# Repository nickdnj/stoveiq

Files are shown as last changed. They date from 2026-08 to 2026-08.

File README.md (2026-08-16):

# StoveIQ -- Open Source Smart Cooking Monitor





An ESP32-S3 + MLX90640 thermal camera that turns any stove into a smart cooktop. Real-time heatmap, per-burner temperature tracking, thermal-aware recipe coaching, and cook session logging -- all running locally with zero cloud dependency.

**No cloud. No subscriptions. No app to install. Just open your browser.**

> **What am I looking at?** This started as a multipurpose kitchen gadget, became a
> commercial stove-safety product, got killed as a product, and came back as a personal
> build that lives over my own stove. That history explains most of the odd shapes in this
> repo -- see [Project History](#project-history). It is not a product, it is not for sale,
> and there is no roadmap to either.

## What it looks like

<table>
<tr>
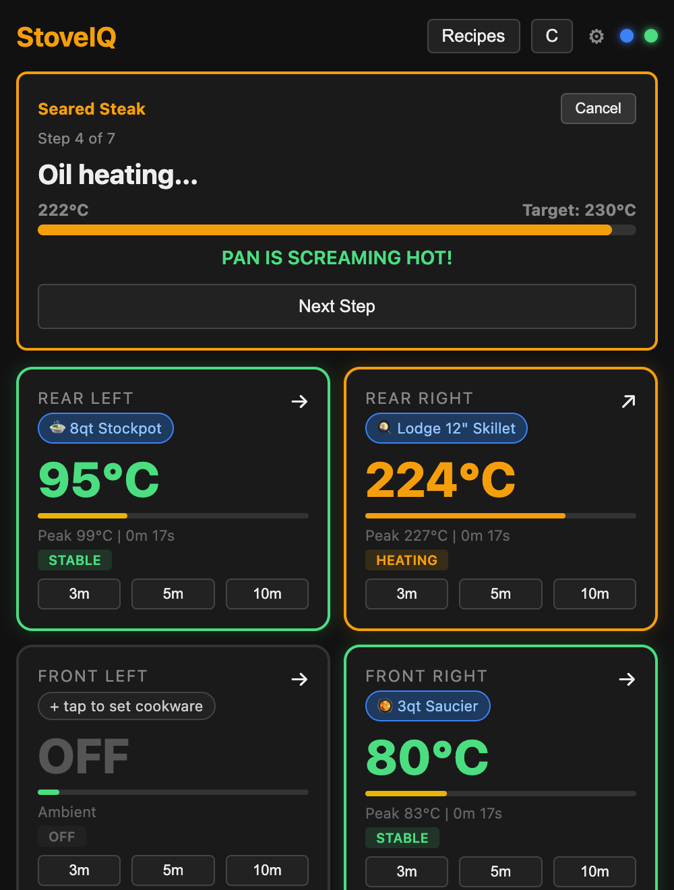
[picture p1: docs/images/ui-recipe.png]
Recipe coaching over live burner cards
<td width="33%"></td>
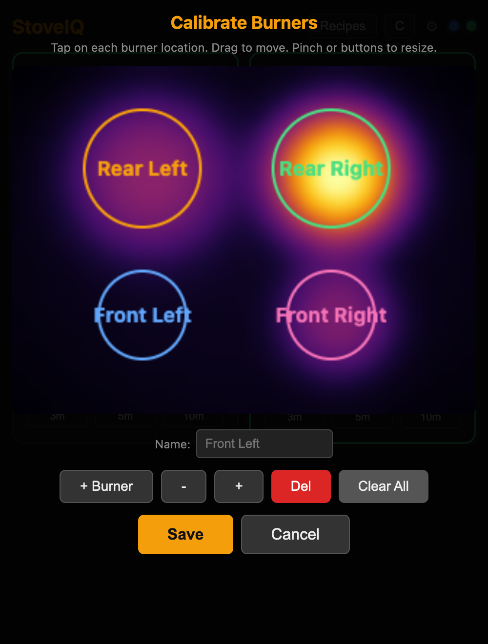
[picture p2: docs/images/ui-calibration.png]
Thermal heatmap with burner zones
<td width="33%"></td>
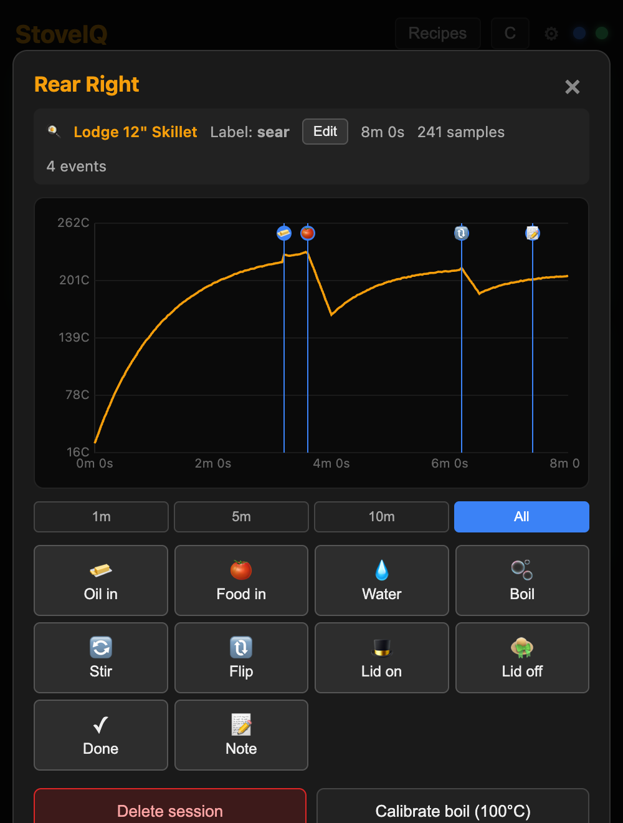
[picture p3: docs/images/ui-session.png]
Annotated cook session curve
<td width="33%"></td>
</tr>
<tr>
<td><b>Recipe coaching.</b> Steps advance on thermal triggers, not timers. Live burner cards underneath.</td>
<td><b>Calibration.</b> The 768-pixel heatmap, bilinear-upscaled, with burner zones tapped onto it.</td>
<td><b>Teaching mode.</b> A finished sear, replayed. The dips are the steak going in and the flip.</td>
</tr>
<tr>
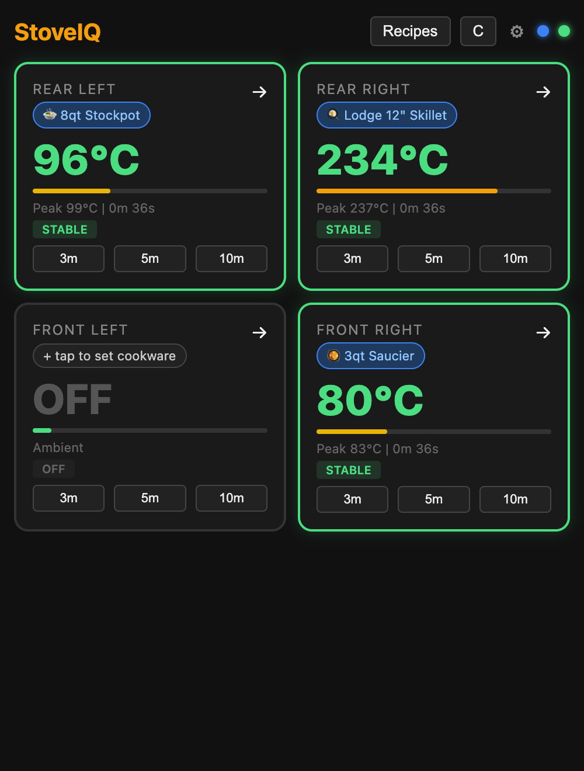
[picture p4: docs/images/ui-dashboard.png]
Burner dashboard
<td></td>
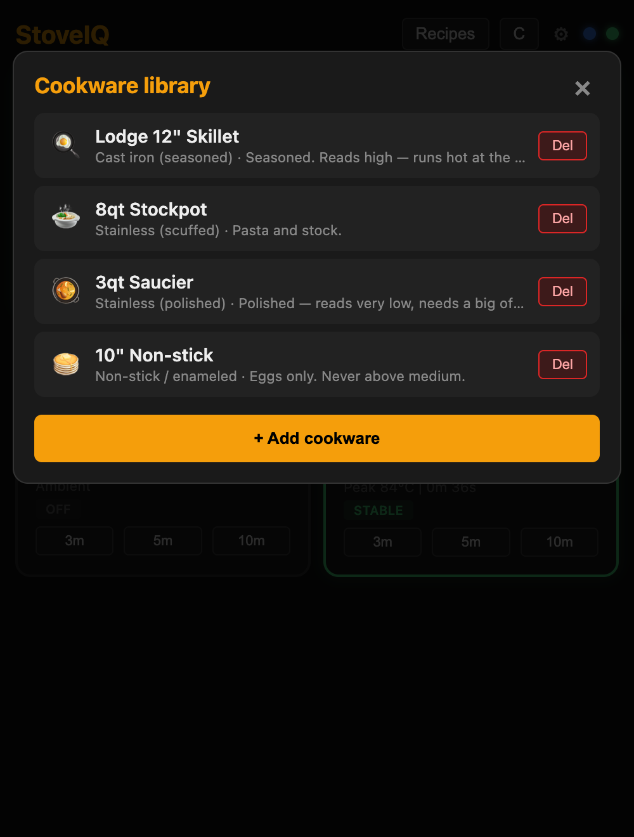
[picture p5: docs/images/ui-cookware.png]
Cookware library
<td></td>
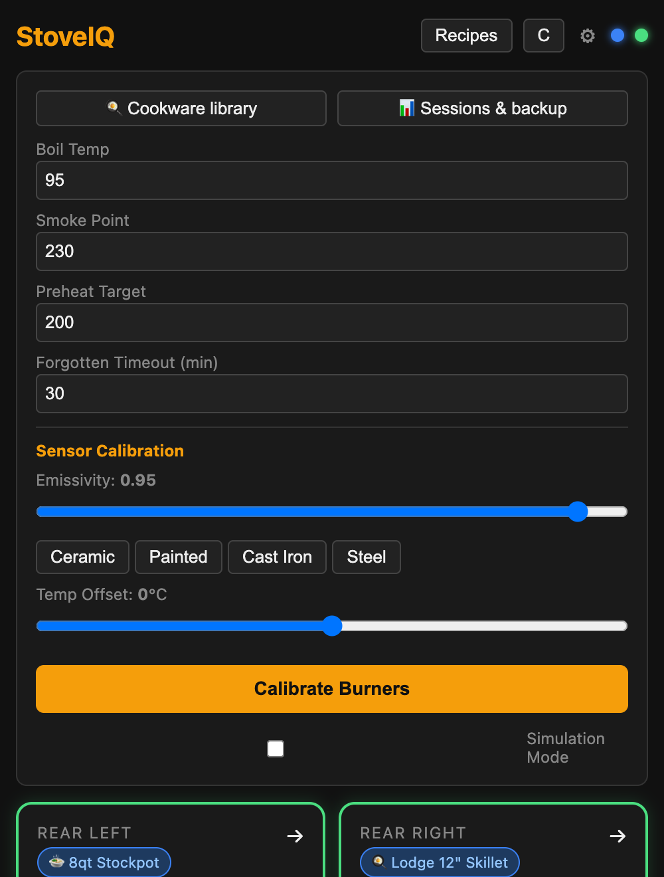
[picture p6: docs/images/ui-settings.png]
Settings and sensor calibration
<td></td>
</tr>
<tr>
<td><b>Dashboard.</b> Per-burner temperature, state, peak, and elapsed time.</td>
<td><b>Cookware library.</b> Emissivity is a property of the pot, so the pot is a first-class object.</td>
<td><b>Settings.</b> Alert thresholds and sensor calibration.</td>
</tr>
</table>

Real UI, synthetic thermal data — regenerate with
[`tools/ui-screenshots/`](tools/ui-screenshots/). Details and provenance in
[`docs/images/`](docs/images/).

## Features

- **Real-time thermal heatmap** -- 768-pixel IR view of your entire cooktop at 4Hz, bilinear-upscaled
- **Per-burner tracking** -- Auto-detects up to 4 burner zones with temperature, state, and trends
- **Recipe coaching** -- JSON state machines with thermal triggers (boil detected, pan preheated, oil in)
- **Cookware calibration** -- Emissivity is per-pot, not per-stove; calibration is a (burner x cookware) pair
- **Teaching mode** -- Tag what happened during a cook ("oil in", "rolling boil") and annotate the temp curve afterward
- **Smart alerts** -- Boil detection, oil smoke point warnings, pan preheated, forgotten burner
- **Runs as a PWA** -- HTTPS + Screen Wake Lock, so your phone stays awake on the counter while you cook
- **100% local** -- All processing on-device, data never leaves your kitchen
- **Works on any stove** -- Gas, electric coil, glass ceramic, induction

## Build Your Own

### Parts List (~$103 from Adafruit)

| Part | Price | Source |
|---|---|---|
| ESP32-S3-DevKitC-1-N8R8 | ~$16 | Adafruit (PID 5312) |
| MLX90640 IR Camera Breakout 110deg FoV | ~$75 | Adafruit (PID 4469) |
| Jumper wires (4x F-F) | ~$1 | Any supplier |
| USB-C cable + 5V adapter | ~$8 | Any supplier |
| 1.5" Schedule 40 PVC pipe (enclosure) | ~$3 | Hardware store |

MLX90640 modules run ~$25-35 on AliExpress, which brings the whole build closer to $50.

A custom PCB meant to replace the devkit lives in [`hardware/pcb/`](hardware/pcb/), but it
is a placement study rather than a board: it has no MCU on it, no routing, and 58 DRC
violations. Build the devkit version. See [Hardware](#hardware) below.

### Wiring

```
ESP32-S3 DevKit     MLX90640 Breakout
--------------      ----------------
3V3          -----> VIN
GND          -----> GND
GPIO 1 (SDA) -----> SDA
GPIO 2 (SCL) -----> SCL
```

### Flash Firmware

```bash
# Install PlatformIO
pip install platformio

# Clone and build
git clone https://github.com/nickdnj/stoveiq.git
cd stoveiq/firmware
pio run -e esp32s3 -t upload
```

The entire web UI is embedded in the firmware binary (`src/web_server.c`), so there is no
separate filesystem upload step. A SPIFFS partition exists and is mounted if populated,
but `firmware/data/` currently ships empty on purpose.

### Connect

1. Power on the device via USB-C
2. Connect to **StoveIQ** WiFi network (open, no password)
3. Open **https://192.168.4.1** in your browser
4. Accept the self-signed certificate warning (one time per device)
5. See your stove in thermal vision

To connect to your home WiFi (for access from any device):
- Use the **ESP BLE Prov** app (iOS/Android) with PoP: `stoveiq-setup`
- Or configure via the web UI settings page

Once on your network the device is reachable at **https://stoveiq.local** via mDNS. Port 80
stays up only to 301-redirect to HTTPS -- the Screen Wake Lock API that keeps your phone
awake while cooking requires a secure context, so plain HTTP is not an option.

## How It Works

```
MLX90640 IR Camera (24x32 pixels, 4Hz)
        |
        v
ESP32-S3 (FreeRTOS)
  Task 1: Sensor Read (Core 1)    -- I2C frame acquisition
  Task 2: Cooking Engine (Core 0) -- CCL burner detection + recipes + alerts
  Task 3: Web Server (Core 0)     -- HTTPS + WebSocket streaming
        |
        v
Browser (any device on WiFi)
  WebSocket binary frames --> Canvas 2D heatmap
  WebSocket JSON status   --> Per-burner dashboard
  localStorage            --> Cookware library, cook sessions, learned offsets
```

### Burner Detection

Connected Component Labeling (CCL) on thresholded thermal image:
1. Binary mask: pixels > ambient + 30C
2. Two-pass CCL with 8-connectivity
3. Filter noise (< 4 pixels) and spurious regions (> 200 pixels)
4. Rank by total heat, track centroids across frames
5. Classify state: OFF / HEATING / STABLE / COOLING via dT/dt

### Calibration

Calibration is two axes, not one:

- **Burner** -- a fixed spatial region of interest on the sensor. Set once by tapping the heatmap.
- **Cookware** -- a thermal property, picked per cook from a user-managed library.

The reason is emissivity: cast iron reads at ~0.95, polished stainless at ~0.05-0.16. A single
global emissivity value is wrong for nearly every pot on the stove. Offsets are stored per
(burner x cookware) pair and applied at display time only -- sessions keep raw temperatures so
the data stays reinterpretable. See [`docs/phase1-cookware-teaching.md`](docs/phase1-cookware-teaching.md).

---

## Hardware

All of it drawn in free and open-source tools -- KiCad for the board, OpenSCAD for the
enclosure. Every image below is generated from source by
[`hardware/render.sh`](hardware/render.sh), not exported by hand.

### Enclosure -- built, and holding the thing up right now

1.5" Schedule 40 PVC pipe split lengthwise. The lower half holds the MLX90640 behind a
14mm window, the upper half holds the devkit, zip ties clamp them together, and the tube
rotates inside a printed cradle so you can aim it and lock the angle.

| Assembled tube | Cabinet bracket | Sensor half |
|---|---|---|
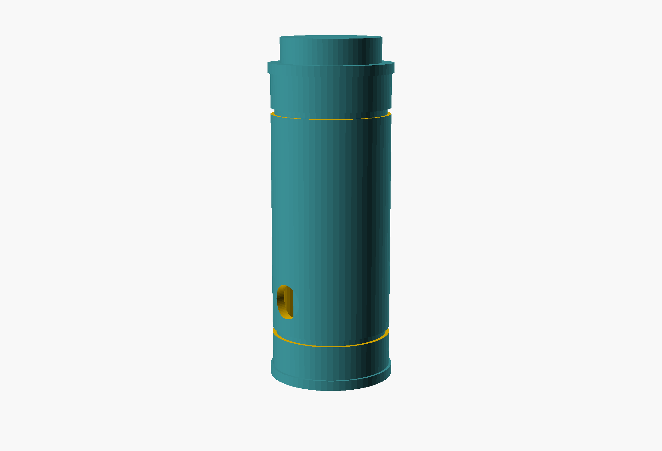
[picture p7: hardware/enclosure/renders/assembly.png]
Assembled enclosure
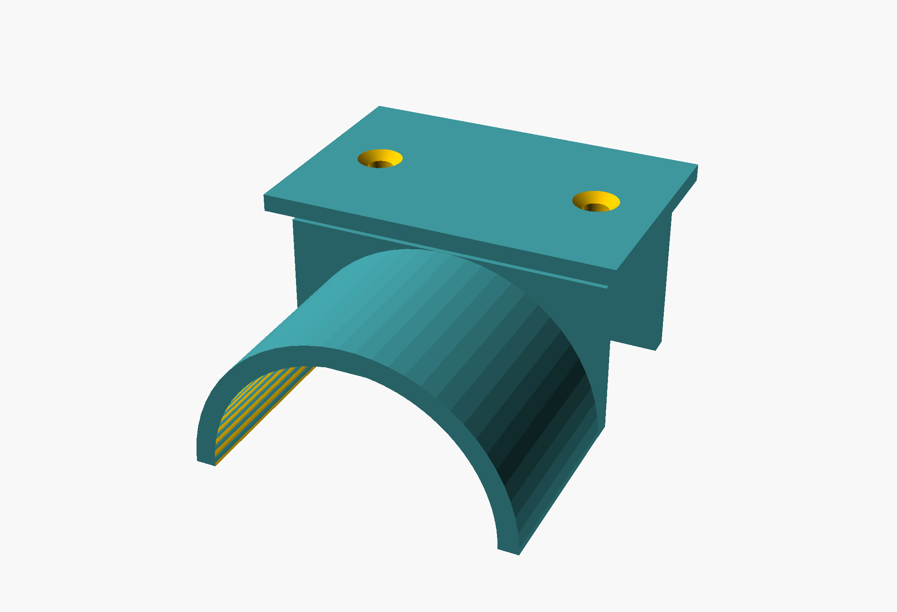
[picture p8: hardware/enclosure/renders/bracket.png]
Mounting bracket
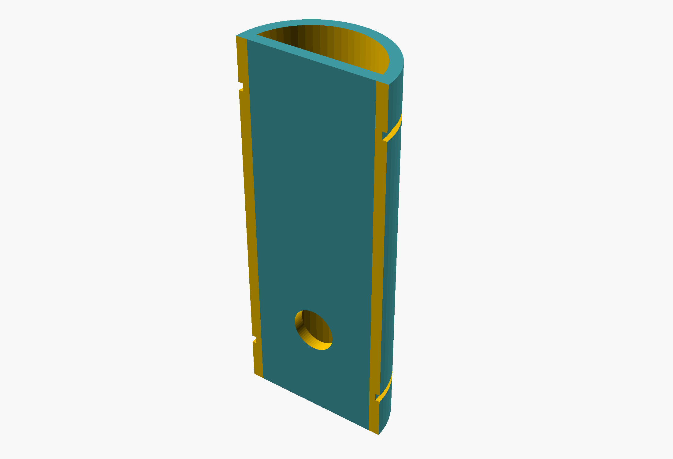
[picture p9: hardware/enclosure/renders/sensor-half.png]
Sensor half
|  |  |  |

Parametric, so you can re-cut it for your own cabinet before printing. Build guide:
[`docs/enclosure-build.md`](docs/enclosure-build.md) · Models and dimensions:
[`hardware/enclosure/`](hardware/enclosure/)

### Custom PCB -- drawn, not finished

A 45x35mm two-layer board to replace the devkit and breakout with one assembly.

| Schematic | 3D | Top copper |
|---|---|---|
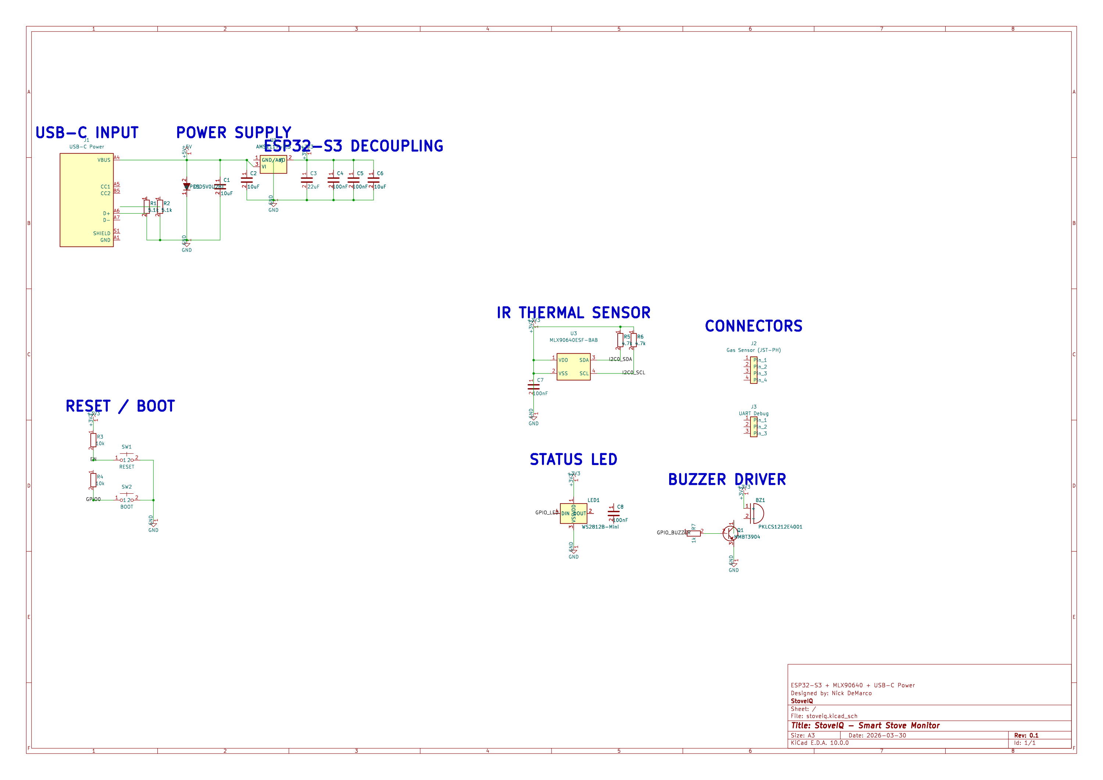
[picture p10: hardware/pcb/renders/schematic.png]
Schematic
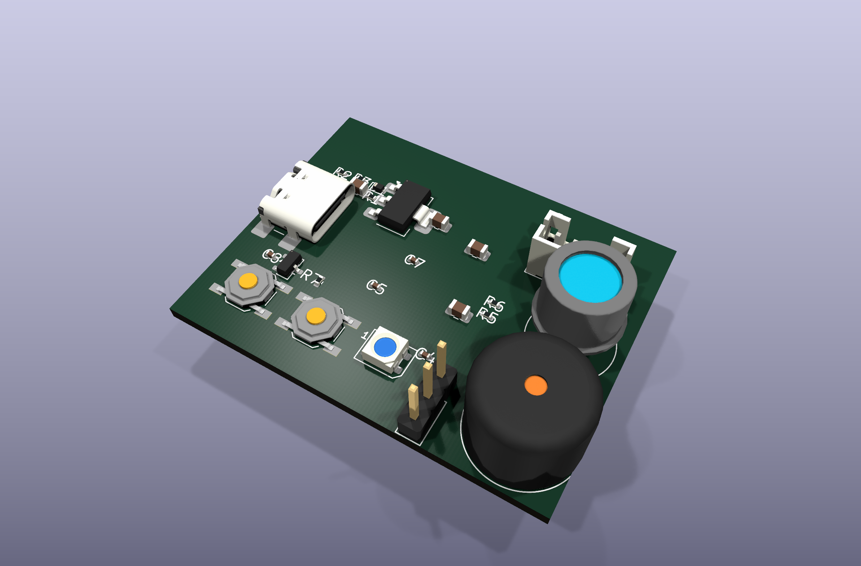
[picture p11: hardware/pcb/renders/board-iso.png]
Board 3D
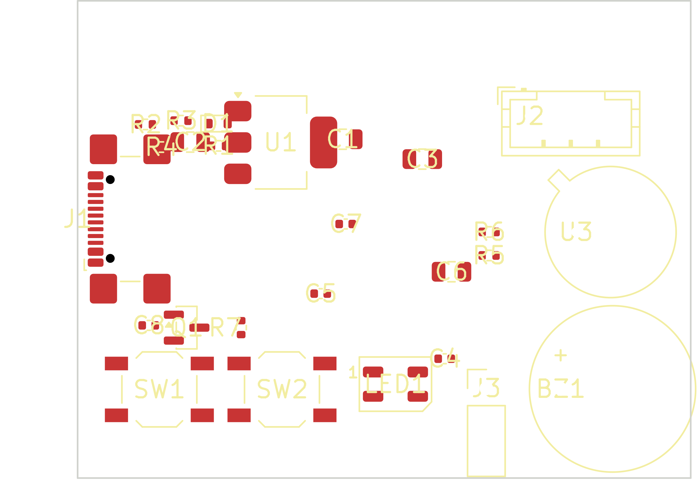
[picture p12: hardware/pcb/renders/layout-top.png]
Top layer
|  |  |  |

That third image is the honest one: **there is not a single trace on this board.** The
support circuitry is captured -- USB-C input, 3.3V regulation, the thermal sensor, an RGB
status LED, a piezo buzzer, reset and boot buttons -- but the ESP32-S3 module was never
placed, so every GPIO net dangles, and nothing is routed.

| | |
|---|---|
| Schematic capture | Partial -- everything except the MCU |
| Routing | None. 0 tracks, 0 vias |
| DRC | 58 violations, including 2 shorts |
| Fabricated | Never |

Full accounting, BOM, and known issues: [`hardware/pcb/README.md`](hardware/pcb/README.md).
If you want to finish it, the files are all here and the licence is permissive.

### Built with

| Tool | Licence | Used for |
|---|---|---|
| [KiCad](https://www.kicad.org/) 10 | GPL-3.0 | Schematic, layout, 3D raytracing, DRC, fab output |
| [OpenSCAD](https://openscad.org/) | GPL-2.0 | Parametric enclosure modelling |
| [FreeCAD](https://www.freecad.org/) | LGPL-2.1 | Alternative enclosure macro |
| [Freerouting](https://freerouting.org/) | AGPL-3.0 | Autorouting attempt |
| [PlatformIO](https://platformio.org/) + [ESP-IDF](https://github.com/espressif/esp-idf) | Apache-2.0 | Firmware build |
| [librsvg](https://gitlab.gnome.org/GNOME/librsvg) | LGPL-2.1 | SVG to PNG for these images |

```bash
brew install kicad openscad librsvg   # or: apt install kicad openscad librsvg2-bin
hardware/render.sh
```

---

## Project History

Worth reading if you are trying to understand why an open-source hobby repo contains a
provisional patent's worth of thermal research, a Kickstarter-grade BOM, and a KiCad board
nobody fabricated. The short version: this project was three different things in four weeks.

| When | What it was |
|---|---|
| Mar 25, 2026 | A multipurpose kitchen gadget idea |
| Mar 26-27, 2026 | A commercial product, then narrowed to a safety-only device |
| Mar 28 - Apr 4, 2026 | A built safety product: firmware, Flutter app, cloud, CI |
| Apr 7, 2026 | Killed -- the commercial case did not survive research |
| Apr 9, 2026 onward | This repo: the original idea, built for one kitchen, in the open |

### 1. The multipurpose version

The first note described a thermal sensor under the range hood doing everything at once:
live heatmap, per-burner temperatures, boil detection, "did I leave the stove on" alerts,
oven monitoring, gas leak sensing, historical usage, a voice assistant hook. It was a
weekend-project wishlist, not a product. The only real constraint was the sensor -- the
MLX90640 was the cheapest array that reads to 300C, which is what ruled out the AMG8833
and set the whole hardware stack.

### 2. It turned into a product

Within a day it grew a full product-development package: PRD, architecture spec, UX spec,
sensor validation study, provisional patent draft, a BOM costed at 100 and 1,000 units
(~$25-37 landed), $199-229 MSRP, and a Kickstarter strategy benchmarked against Inirv
React's $176K raise. Cooking a thing for yourself had become launching a thing at people.

### 3. GStack narrowed it to a safety device

I ran the plan through GStack reviews -- an AI review pipeline (`/office-hours`,
`/plan-ceo-review`) that interrogates a plan the way a skeptical founder or investor would.
The verdict was uncomfortable and correct:

- **The buyer is not the cook.** Safety drives the purchase decision; cooking features drive
  daily engagement. The primary user is the adult child of a parent living alone, not me.
- **The MVP was still too broad.** It got stripped to a single question: *"Is Mom's stove on?"*
  Whole-frame max temperature, a duration timer, a push notification, a buzzer. That was all.
- **Everything I actually wanted got deferred.** Heatmap, per-burner detection, boil detection,
  calibration wizard, cooking history -- all pushed to "v2."

Fair review, honestly followed. Over the next week I built exactly that: safety-monitor
firmware, a Flutter app, Firebase push, MQTT, OTA updates, golden-vector tests, a security
review pass, CI. It lives in an archived private repo. None of it is in this one.

### 4. GStack then killed the product

A patent and competitive research pass on April 7 turned up
[Pippa Technologies](https://www.mypippa.me/) -- a UK company with **EP3908785B1**, granted
February 2025, covering IR thermal imaging for cooking appliance monitoring. Dragons' Den
funded, shipping at GBP 179.99 plus a subscription, on Amazon UK, with a US expansion in
progress. Meanwhile Cooksy, the closest thermal-cooking product, appeared to be retreating
from its $299-699 cooking-only position.

Add the rest of the arithmetic for a solo builder: FCC plus likely UL certification, and
open-ended liability for a device whose entire promise is *"we will warn you before the fire."*
The commercial case did not hold.

*None of that is a legal conclusion.* No freedom-to-operate opinion was ever commissioned.
It was a judgment call -- the kind where you do not want to find out the hard way.

I then researched seven other markets for the identical hardware stack: electrical panel
thermal monitoring (the best-graded of them, with a proven insurance distribution channel),
3D printer fire detection, dryer lint fires, EV charging, solar hotspots, beehives, server
rooms. All of them were more viable than the stove. I did not chase any of them, because
none of them were the thing I wanted in my kitchen.

### 5. Pivot back to just... my stove

On April 9 the project restarted as what it had been on day one, minus the ambition.

**Dropped:** company, Kickstarter, patent, cloud, MQTT, Flutter app, app store,
subscription, caregiver dashboard, and every safety claim.

**Kept:** the hardware, and the thing I actually wanted.

A fresh public repo was necessary anyway -- the old one had WiFi and MQTT credentials
committed in its history -- so it was archived private and this one started clean. The
happy accident: every cooking feature GStack had correctly cut as "v2 nice-to-have" became
the entire point again, because there was no longer a product for them to be a distraction
from.

That is why this repo is local-first, ships no cloud, makes no safety promises, and serves
its UI off an ESP32 instead of an app store.

### 6. Where it is now

Mounted over my stove and used for real cooking. Since the pivot it has grown recipe state
machines, HTTPS so the phone's wake lock works, cookware-based calibration, and a teaching
mode that captures labeled cook sessions -- a corpus for phase-aware calibration later. The
KiCad board and enclosure models landed in August 2026. The enclosure is printed and in
use; the board never got past component placement and has never been fabricated.

### Does it have economic value?

Honest answer: no idea, and I stopped trying to find out -- which was the point of stopping.

What I do know: as a commercial *safety* device the path is blocked, expensive, and legally
exposed for one person. As a *cooking* product the nearest comparable retreated from that
price point. As a personal build it has been worth every hour.

The software is MIT and the hardware is CERN-OHL-S-2.0. If you see the market I could not,
the files are all here -- schematics, board, enclosure, firmware, recipes. Take it.

---

## Repo Structure

```
stoveiq/
  firmware/
    src/              # Firmware source (C, ESP-IDF) -- web UI embedded in web_server.c
    include/          # Shared headers
    test/             # Unity test suite
    emulator/         # Desktop thermal emulator + scenarios
    lib/MLX90640/     # Melexis sensor driver
  hardware/
    render.sh         # Regenerates every hardware image from source
    pcb/              # KiCad 10 project -- schematic, layout, fab outputs
      renders/        #   Generated: schematic, layer plots, 3D views
    enclosure/        # PVC tube + wedge box (OpenSCAD, FreeCAD macro)
      renders/        #   Generated: assembly, parts, bracket
  enclosure/          # Byte-identical copy of hardware/enclosure/stoveiq_enclosure.scad,
                      # kept so the old path still resolves
  tools/
    ui-screenshots/   # Runs the web UI on a desktop with synthetic thermal data
  recipes/            # Community recipe JSON state machines + schema
  docs/
    images/           # UI screenshots used on this page
  video/              # Unproduced draft: script, storyboard, assembly pipeline
```

Enclosure files are OpenSCAD/FreeCAD sources, not pre-sliced STLs -- render your own.

## Development

### Desktop Emulator

Build and run without hardware using the thermal scene emulator:

```bash
cd firmware
pio run -e emulator
.pio/build/emulator/program
```

### Run Tests

```bash
cd firmware
pio test -e emulator
```

23 tests across two suites -- `test/test_sensor/` (frame parsing, max/ambient extraction,
emulator scenarios) and `test/test_cooking_engine/` (burner detection, state machine).

### Building from a fresh clone

The self-signed TLS certificate is not in the repo -- `firmware/src/certs.h` embeds a
private key, so it is generated rather than committed. Run this once per clone before the
first ESP32 build:

```bash
./scripts/gen-cert.sh
```

### See the web UI without hardware

The interface is embedded in the firmware as a C string, and the emulator build excludes
`web_server.c` -- so there is normally no way to look at the UI without flashing a board.
[`tools/ui-screenshots/`](tools/ui-screenshots/) extracts it and serves it locally against
a synthetic thermal feed that speaks the firmware's real WebSocket protocol.

```bash
cd tools/ui-screenshots
pip install aiohttp
python3 extract.py && python3 server.py --recipe   # http://127.0.0.1:8770
```

## Contributing

Contributions welcome -- especially:
- Recipes (see [`recipes/README.md`](recipes/README.md) for the schema and PR template)
- Web UI improvements (`firmware/src/web_server.c`)
- New cooking alert types
- Enclosure variants for different mounting scenarios
- Translations

Bear in mind what this project is: a personal build shared in the open. Issues and PRs get
looked at when there is time, and "does this make it better in my kitchen?" is a legitimate
review criterion.

## License

- **Software:** [MIT](LICENSE-SOFTWARE)
- **Hardware:** [CERN-OHL-S-2.0](LICENSE-HARDWARE)

## Inspired By

- [Combustion Inc](https://combustion.inc/) -- Smart cooking thermometer with predictive algorithms (internal meat temps via probe). StoveIQ provides the complementary view: surface thermal imaging of the entire cooktop from above.

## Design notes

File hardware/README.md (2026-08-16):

# StoveIQ Hardware

Everything mechanical and electrical, designed end-to-end in free and
open-source tools. No licence, no seat, no cloud account — clone the repo and
open the files.

| Directory | What | Tool | Status |
|---|---|---|---|
| [`pcb/`](pcb/) | Custom ESP32-S3 + MLX90640 board, 45 × 35 mm | KiCad 10 | **Placement study** — no MCU, unrouted, 58 DRC violations |
| [`enclosure/`](enclosure/) | PVC split-tube housing + cabinet bracket | OpenSCAD | **Built** — this is what is mounted over the stove |
| [`enclosure/`](enclosure/) | Wedge box for the custom board | OpenSCAD | Modelled only |

The honest summary: **the enclosure is real and the board is not.** The device
in daily use is an ESP32-S3 devkit and an MLX90640 breakout wired together and
zip-tied inside a length of PVC pipe. The custom PCB was drawn to replace them
and never finished.

---

## The toolchain

| Tool | Licence | Used for |
|---|---|---|
| [KiCad](https://www.kicad.org/) 10 | GPL-3.0 | Schematic capture, PCB layout, 3D raytracing, DRC, fab output |
| [OpenSCAD](https://openscad.org/) 2021.01 | GPL-2.0 | Parametric enclosure modelling and rendering |
| [FreeCAD](https://www.freecad.org/) | LGPL-2.1 | Alternative enclosure macro (see `enclosure/`) |
| [Freerouting](https://freerouting.org/) | AGPL-3.0 | Autorouting attempt (`pcb/stoveiq.dsn` / `.ses`) |
| [librsvg](https://gitlab.gnome.org/GNOME/librsvg) | LGPL-2.1 | SVG → PNG for the images on GitHub |
| [PlatformIO](https://platformio.org/) + [ESP-IDF](https://github.com/espressif/esp-idf) | Apache-2.0 | Firmware build (see `../firmware/`) |

Every image in this repository is generated from source by
[`render.sh`](render.sh) — no screenshots taken by hand, nothing drawn in a
proprietary tool.

```bash
# macOS
brew install kicad openscad librsvg

# Debian / Ubuntu
apt install kicad openscad librsvg2-bin

# Then, from the repo root
hardware/render.sh
```

Outputs land in `pcb/renders/` and `enclosure/renders/` and are committed, so
reading the GitHub page never requires installing anything.

---

## Where to start

- **Building one?** You want the devkit parts list in the
  [root README](../README.md#build-your-own) and the
  [enclosure build guide](../docs/enclosure-build.md).
- **Looking at the board?** [`pcb/README.md`](pcb/README.md) — full BOM,
  schematic, layout plots, and a frank list of what is wrong with it.
- **Printing a housing?** [`enclosure/README.md`](enclosure/README.md) —
  dimensions, print settings, STL export commands.

## Licence

Hardware is [CERN-OHL-S-2.0](../LICENSE-HARDWARE). Firmware is
[MIT](../LICENSE-SOFTWARE).

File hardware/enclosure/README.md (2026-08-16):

# StoveIQ Enclosures

Two parametric enclosure designs, both written in **OpenSCAD** — free software,
plain text, diffable. Neither ships as a pre-sliced STL: render your own from
source so you can change the dimensions for your cabinet first.

| | Design | For | Status |
|---|---|---|---|
| **A** | [PVC split-tube](#a--pvc-split-tube) | ESP32-S3 devkit + MLX90640 breakout | Built and mounted; the documented build |
| **B** | [Wedge box](#b--wedge-box) | The custom [PCB](../pcb/) | Modelled only — the board it houses is unfinished |

Design A is what you want if you are following the parts list in the root
README. Design B exists for the custom board and cannot be used until that board
does.

---

## A — PVC split-tube

1.5″ Schedule 40 PVC pipe, split lengthwise into two D-shaped halves. The lower
half carries the MLX90640 and its 14 mm camera window; the upper half carries the
ESP32-S3 devkit and the USB-C exit notch. Zip ties through the outer-diameter
grooves clamp the halves together, and the finished tube drops into a printed
cradle that screws to the underside of a cabinet. Rotate the tube in the cradle
to aim at the stove, then tighten.

The circular cross-section is the whole point: aiming is a rotation, and a
rotation is trivial to lock.

**Source:** [`stoveiq_pvc_enclosure.scad`](stoveiq_pvc_enclosure.scad) ·
**Build guide:** [`../../docs/enclosure-build.md`](../../docs/enclosure-build.md)

| Assembled | Mounting bracket |
|---|---|
| Assembled tube | Cradle bracket |
| Both halves mated, end caps fitted. The 14 mm camera window and the two zip-tie grooves are visible. | Screws to the cabinet underside on 40 mm centres; the tube rotates inside the cradle to aim. |

| Sensor half | ESP32 half | End cap |
|---|---|---|
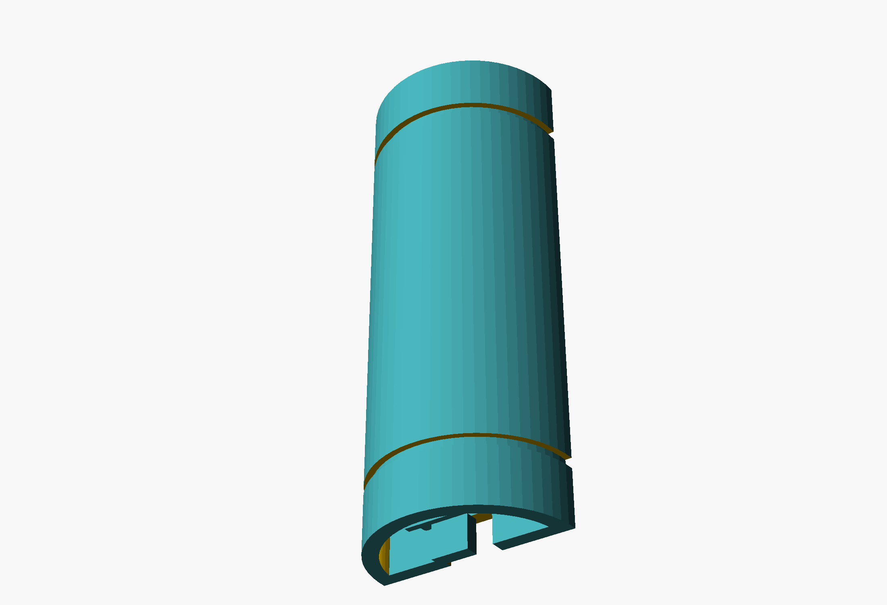
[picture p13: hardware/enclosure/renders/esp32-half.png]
ESP32 half
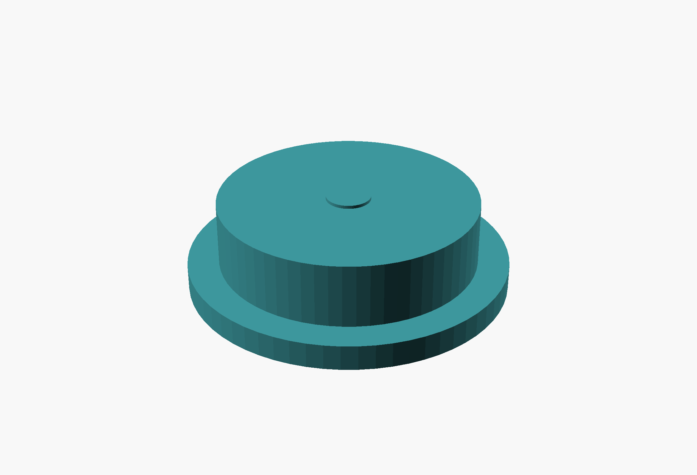
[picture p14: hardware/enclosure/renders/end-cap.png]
End cap
| Sensor half |  |  |
| Camera window plus four M2 standoffs for the breakout. | USB-C exit notch and alignment tabs. | Press-fit spigot, optionally vented. |

### Key dimensions

| Parameter | Value | Note |
|---|---|---|
| `PIPE_OD` / `PIPE_ID` | 48.26 / 40.89 mm | 1.5″ Sch 40, so real pipe interchanges with printed halves |
| `PIPE_L` | 120 mm | Cut length |
| `WALL` | 3.685 mm | Matches the real PVC wall |
| `WIN_D` | 14 mm | Camera window — clears the 110° field of view |
| `WIN_Z` | 30 mm | Window position from the sensor end |
| `GROOVE_Z1` / `Z2` | 15 / 105 mm | Zip-tie grooves |
| `TAB_Z1` / `Z2` | 20 / 100 mm | Alignment tabs, 0.3 mm clearance |
| `BKT_HOLE_SP` | 40 mm | Bracket screw spacing, #8 or M4 |

### Two ways to build it

- **Fully printed** — print both halves in PETG or ASA. No pipe needed.
- **Hybrid** — buy 6″ of real 1.5″ PVC, cut it in half lengthwise with a
  hacksaw, and print only the end caps and the bracket. Cheaper and stiffer.

**Print settings:** 0.2 mm layers, 35 % gyroid infill, 3 perimeters, no supports
— every surface is designed to print face-down without them. PETG indoors, ASA
if it will see heat or sun.

---

## B — Wedge box

A closed box for the custom PCB. The top face is flat and screws to the cabinet;
the bottom face tilts 35° so the sensor looks down and forward at the cooktop
without the whole box needing to be angled. Side vents let convected heat out.

**Source:** [`stoveiq_enclosure.scad`](stoveiq_enclosure.scad)

| Isometric | Underside | Side profile |
|---|---|---|
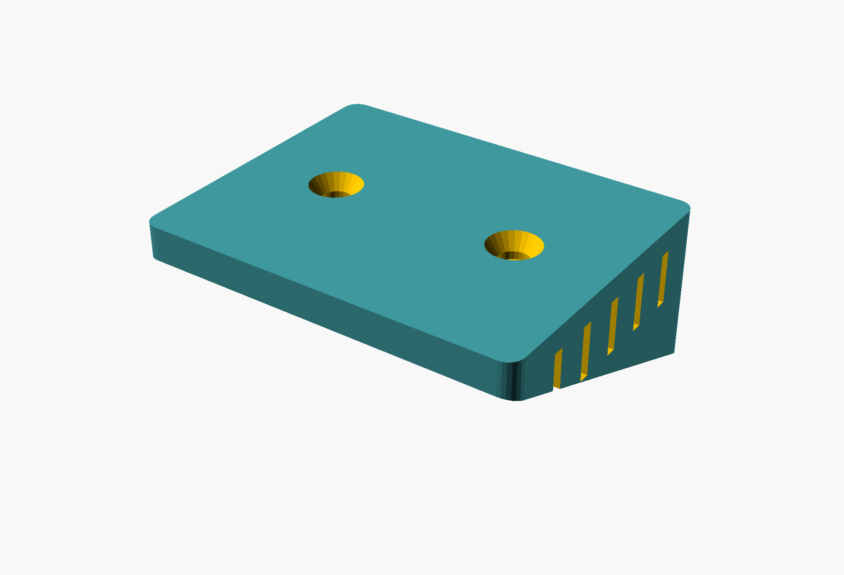
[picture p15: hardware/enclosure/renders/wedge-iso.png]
Wedge isometric
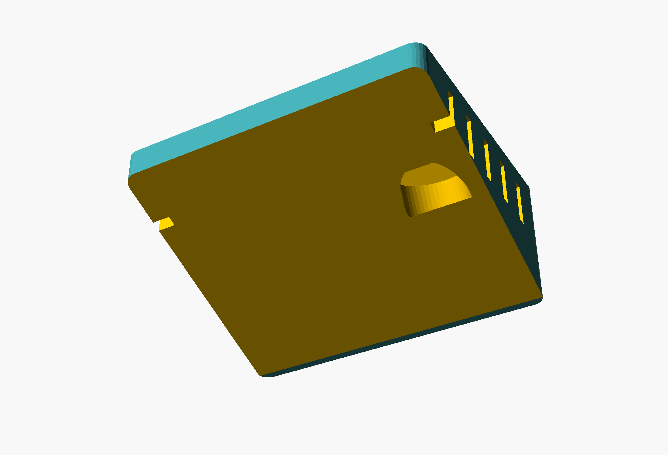
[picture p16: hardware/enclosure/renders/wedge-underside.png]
Wedge underside
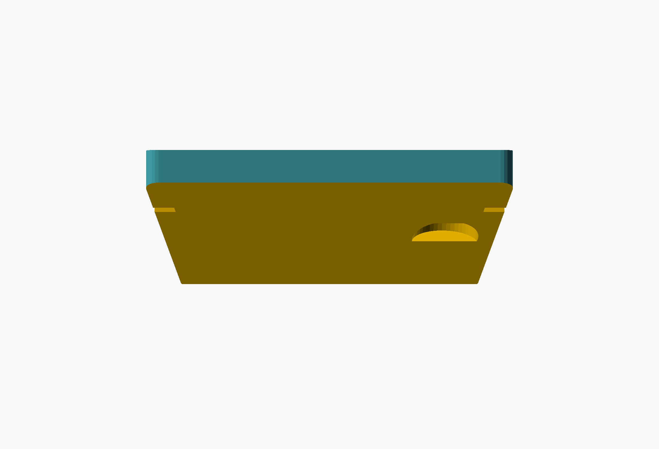
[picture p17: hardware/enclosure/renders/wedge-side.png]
Wedge side
|  |  |  |
| Flat cabinet face with two countersunk mounting holes. | The 35° face carrying the 10 mm IR aperture, plus side vents. | The wedge taper. |

### Key dimensions

| Parameter | Value | Note |
|---|---|---|
| `pcb_w` × `pcb_d` | 45 × 35 mm | Matches the [PCB](../pcb/) outline |
| `sensor_angle` | 35° | Camera tilt from vertical |
| `ir_aperture` | 10 mm | Wider than the TO-39 can, for FoV margin |
| `wall` | 2.0 mm | Shell thickness |
| `gap` | 0.5 mm | PCB clearance all round |
| `standoff_h` | 3 mm | Board height above the floor |

Outer size and wedge heights are derived from these — OpenSCAD `echo`es them at
render time.

> This design targets a board that has no MCU and no routing. Treat it as a
> volume study until [`../pcb/`](../pcb/) is finished.

---

## Rendering and printing

```bash
# Regenerate every image above
hardware/render.sh

# Export a printable STL (pick the part you want)
openscad -o sensor_half.stl -D SHOW_ASSEMBLY=false -D SHOW_SENSOR_HALF=true \
         stoveiq_pvc_enclosure.scad
openscad -o bracket.stl     -D SHOW_ASSEMBLY=false -D SHOW_SENSOR_HALF=false \
         -D SHOW_BRACKET=true stoveiq_pvc_enclosure.scad

# Or open it and use the GUI
openscad stoveiq_pvc_enclosure.scad
```

Render flags for the PVC design: `SHOW_SENSOR_HALF`, `SHOW_ESP32_HALF`,
`SHOW_END_CAP`, `SHOW_BRACKET`, `SHOW_ASSEMBLY`, `SHOW_COMPONENTS` (ghost PCBs
for clearance checking). The wedge design takes no flags — it renders the whole
box.

### A note on `stoveiq_pvc_enclosure.FCMacro`

A FreeCAD macro that builds the same tube. It has not been kept in step with the
`.scad`, which is the source of truth for the renders above.

---

## Licence

Hardware in this directory is [CERN-OHL-S-2.0](../../LICENSE-HARDWARE).

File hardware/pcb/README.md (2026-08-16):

# StoveIQ PCB

A 45 × 35 mm two-layer board that replaces the ESP32-S3 devkit and the MLX90640
breakout with a single assembly. Drawn in **KiCad 10**, entirely with free and
open-source tools.

> ### Status: placement study, not a fabricable board
>
> Read this before you send anything to a fab house. The support circuitry is
> captured and the parts are placed, but the board is **not finished**:
>
> | | |
> |---|---|
> | Schematic capture | Partial — power, USB-C, sensor, LED, buzzer, buttons |
> | **MCU** | **Absent.** There is no `U2`. See [below](#the-missing-mcu). |
> | Routing | **None.** 0 track segments, 0 vias. 13 copper zones only. |
> | DRC | **58 violations**, including 2 hard shorts |
> | Fabricated | Never |
>
> Everything below documents what is genuinely in the files. Nothing here has
> been built, and the board as committed would not work if it were.

---

## What it looks like

| Schematic |
|---|
| Schematic |
| Power in, regulation, sensor, indicators. Click through for the PDF. Note there is no MCU sheet — that is the gap described below. |

| 3D — isometric | Top | Bottom |
|---|---|---|
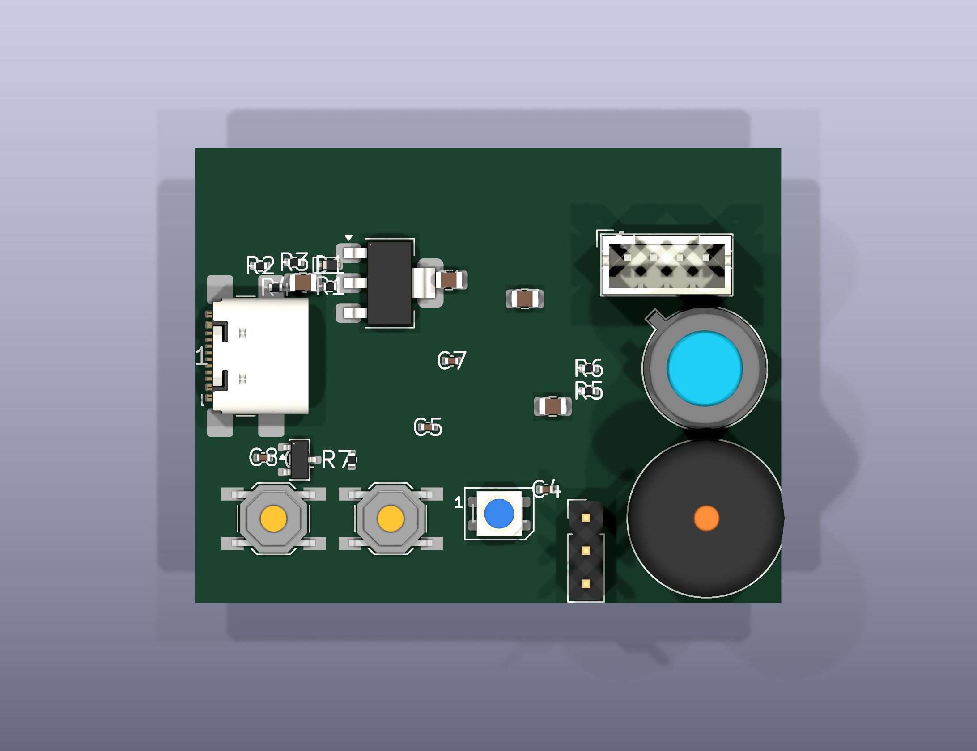
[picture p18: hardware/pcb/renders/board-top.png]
Board top
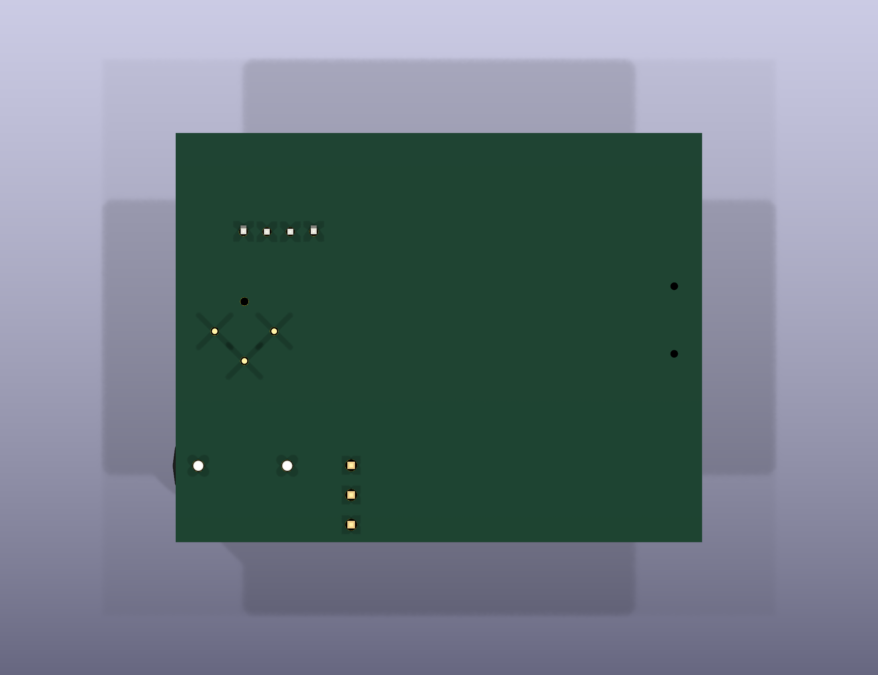
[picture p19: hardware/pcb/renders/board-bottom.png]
Board bottom
| Board isometric |  |  |

| Copper + silkscreen (top) | Assembly drawing |
|---|---|
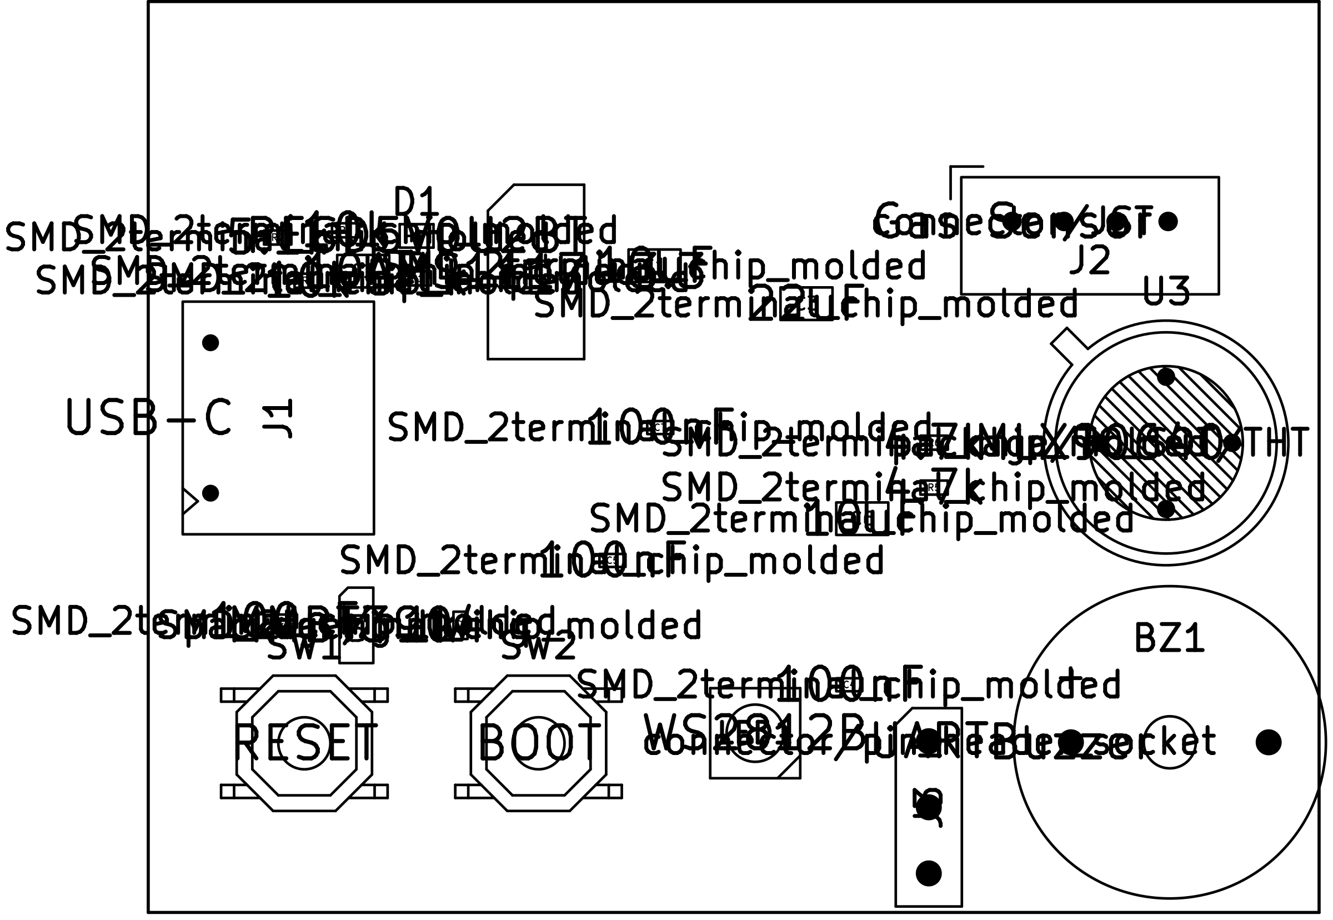
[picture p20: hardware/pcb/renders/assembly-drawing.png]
Assembly drawing
| Top layer |  |

The top-layer plot is the honest one: **there is not a single trace on it.**
Every pad is an island. The large empty region on the left is where the MCU
would go if it existed, and the colliding designators around `R1`–`R4` are the
`silk_overlap` DRC violations.

Regenerate all of these with [`../render.sh`](../render.sh).

---

## The missing MCU

The schematic contains `U1` (the LDO) and `U3` (the thermal sensor). It does not
contain `U2`. An earlier version of this file documented `U2` as an
`ESP32-S3-WROOM-1-N8R8`; that row described a part that was never placed, and it
has been removed from the bill of materials below.

The practical consequence is that these nets are driven by nothing:

| Net | Should connect to | Currently |
|---|---|---|
| `I2C0_SDA` / `I2C0_SCL` | ESP32-S3 GPIO 1 / 2 | Sensor + pull-ups only, no master |
| `GPIO_LED` | ESP32-S3 GPIO 38 | WS2812B data-in, floating |
| `GPIO_BUZZER` | ESP32-S3 GPIO 39 | Q1 base resistor, floating |
| `EN` | ESP32-S3 enable | Pull-up + reset button, floating |
| `GPIO0` | ESP32-S3 boot select | Pull-up + boot button, floating |
| `USB D+` / `D-` | ESP32-S3 GPIO 20 / 19 | USB-C connector, unrouted |

Finishing the board means adding the module symbol and footprint, wiring those
nets, resolving the shorts, and routing. That work has not been done.

---

## Bill of materials

As captured in `stoveiq.kicad_sch`. Reference designators match the schematic and
the assembly drawing above.

| Ref | Part | Package | Purpose |
|-----|---|---|---|
| U1 | AMS1117-3.3 | SOT-223 | 5 V → 3.3 V LDO regulator |
| U3 | MLX90640ESF-BAB | TO-39, 4-lead | 32 × 24 IR thermal array, 110° FoV |
| J1 | GCT USB4110-GF-A | SMD | USB-C receptacle, power input |
| J2 | B4B-PH-K-S | JST-PH 1×4 | Gas sensor expansion (I²C bus 1) |
| J3 | Pin header 1×3 | 2.54 mm | UART debug (omit in production) |
| LED1 | WS2812B-Mini | PLCC4 | RGB status LED |
| BZ1 | PKLCS1212E4001 | 12 mm | Piezo buzzer |
| Q1 | MMBT3904 | SOT-23 | Buzzer NPN driver |
| D1 | PESD5V0U2BT | SOD-523 | USB ESD protection |
| SW1 / SW2 | Tactile switch | 6 mm | Reset / boot mode |
| R1–R2 | 5.1 kΩ | 0402 | USB-C CC pull-downs |
| R3–R4 | 10 kΩ | 0402 | EN / GPIO0 pull-ups |
| R5–R6 | 4.7 kΩ | 0402 | I²C pull-ups (bus 0) |
| R7 | 1 kΩ | 0402 | Buzzer base resistor |
| C1–C2 | 10 µF / 10 V | 0805 | Input + LDO input caps |
| C3 | 22 µF / 6.3 V | 0805 | LDO output cap |
| C4–C5 | 100 nF | 0402 | MCU decoupling (for the absent U2) |
| C6 | 10 µF | 0805 | Bulk decoupling |
| C7–C8 | 100 nF | 0402 | MLX90640 + LED decoupling |

**Not in the BOM, but required for a working board:** an
ESP32-S3-WROOM-1-N8R8 module and its antenna keep-out.

### Intended ESP32-S3 pin assignment

Carried over from the devkit build in `firmware/`, kept here as the target for
whoever wires up the MCU. These match the pins the firmware actually uses.

| GPIO | Function |
|---|---|
| 1 / 2 | I²C0 SDA / SCL — MLX90640 |
| 3 / 4 | I²C1 SDA / SCL — gas sensor expansion (J2) |
| 19 / 20 | USB D− / D+ — native USB-JTAG |
| 38 | WS2812B data |
| 39 | Buzzer, via Q1 |
| 43 / 44 | UART0 TX / RX — debug header (J3) |
| 0 | Boot select (SW2) |
| EN | Reset (SW1) |

---

## Known issues

Reproduce with `kicad-cli pcb drc stoveiq.kicad_pcb`. The report in
[`stoveiq-drc.rpt`](stoveiq-drc.rpt) was generated 2026-03-30.

**Shorts (2)** — these are electrical faults, not cosmetic:

- `EN` shorted to `GPIO0` across the SW1 / SW2 pads. Holding reset would also
  pull the chip into download mode.
- `+3V3` shorted to U1's GND/Adj pad — the regulator output tied to its own
  ground reference.

**Clearance and mask (21)** — 9 clearance violations down to 0.00 mm (J1's own
pads overlap D1's), 8 solder-mask bridges, 4 copper-to-edge violations.

**Silkscreen (26)** — designators overlapping pads and each other, and running
off the board edge. Visible in the top-layer plot above.

**Courtyards (9)** — U3 overlaps J2, and BZ1 overlaps U3. The parts physically
collide at the right-hand edge; you can see it in the isometric render.

**Unconnected (6)** — the dangling MCU nets listed earlier.

### Two 3D models are substituted for rendering

KiCad 10 ships these footprints but not their STEP files, so the board rendered
with bare pads until they were repointed. This affects the *pictures only* — the
footprints, pads, and BOM are unchanged.

| Footprint | Missing model | Substituted with |
|---|---|---|
| `USB_C_Receptacle_GCT_USB4110` | `USB_C_Receptacle_GCT_USB4110.step` | `USB_C_Receptacle_GCT_USB4105-xx-A_16P_TopMnt_Horizontal.step` — same GCT 16-pin top-mount family |
| `TO-39-4_Window` | `TO-39-4_Window.step` | `TO-39-3_Window.step` — identical can and window, one fewer lead |

---

## Working with the files

```bash
# Open in KiCad
kicad hardware/pcb/stoveiq.kicad_pro

# Re-run design rule check
cd hardware/pcb && kicad-cli pcb drc stoveiq.kicad_pcb

# Regenerate every image in renders/
hardware/render.sh
```

`stoveiq.dsn` and `stoveiq.ses` are a [Freerouting](https://freerouting.org/)
round-trip from March 2026. The `.ses` was exported but never imported back into
the board, which is why the layout still has no tracks.

`stoveiq_test.kicad_pcb` / `.kicad_pro` are a scratch project, not part of the
design.

### Altium import

KiCad projects import directly: **File → Import → KiCad Design Files**, then
select `stoveiq.kicad_pro`. Given the state of the board, you would be importing
a placement, not a layout.

---

## Licence

Hardware in this directory is [CERN-OHL-S-2.0](../../LICENSE-HARDWARE).

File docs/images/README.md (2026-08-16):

# Screenshots

The StoveIQ web interface, captured in Chrome at a 440 × 660 viewport.

**These are the real UI, driven by synthetic thermal data.** Every element is
served from the HTML embedded in `firmware/src/web_server.c` — nothing was
mocked up, redrawn, or retouched. The temperatures behind it come from
[`tools/ui-screenshots/`](../../tools/ui-screenshots/), which replays a
plausible four-burner cooktop over the firmware's own WebSocket protocol. The
cookware library and the cook session are seeded fixtures.

No photograph in this repository shows the physical device. The stills under
`video/assets/` are AI-generated illustrations from an unproduced video draft
and are not hardware documentation.

| File | Shows |
|---|---|
| `ui-dashboard.png` | Four burner cards with calibrated names, cookware, live temperatures and state |
| `ui-recipe.png` | Recipe coaching card — "Seared Steak" step 4, progress toward the 230 °C target |
| `ui-calibration.png` | The thermal heatmap with burner zones overlaid, as used to place them |
| `ui-session.png` | A completed cook replayed as an annotated temperature curve |
| `ui-cookware.png` | The cookware library, with emissivity class per item |
| `ui-settings.png` | Alert thresholds and sensor calibration |

## Regenerating

```bash
cd tools/ui-screenshots
python3 extract.py
python3 server.py --recipe
```

Then seed `localStorage` as described in that directory's README, size the
viewport to 440 × 660, and capture. See
[`tools/ui-screenshots/README.md`](../../tools/ui-screenshots/README.md).

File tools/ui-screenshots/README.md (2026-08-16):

# UI screenshot harness

Runs the StoveIQ web UI on your desktop, without an ESP32 and without a stove,
so the screenshots in [`docs/images/`](../../docs/images/) can be regenerated
whenever the UI changes.

**The UI is real. The thermal data is not.** Every pixel of interface comes
straight out of `firmware/src/web_server.c`; the temperatures behind it are
synthesised by `server.py`. Nothing here runs on the device or ships in the
firmware binary.

## Why this exists

The web UI is embedded in the firmware as a C string literal, and the native
emulator build (`pio run -e emulator`) deliberately excludes `web_server.c` —
so there is no way to see the interface without flashing hardware and standing
at a hot stove. This harness closes that gap.

## Use

```bash
cd tools/ui-screenshots
pip install aiohttp

python3 extract.py          # web_server.c  ->  index.html
python3 server.py           # serve on http://127.0.0.1:8770
python3 server.py --recipe  # ...with the recipe coaching card active
```

Open <http://127.0.0.1:8770> in a browser at a phone-sized viewport (the UI is
capped at 500 px wide). A 440 × 660 viewport is what the committed screenshots
use.

## How it works

`extract.py` walks the `FALLBACK_HTML[]` literal chain in `web_server.c`,
strips the C comments between the fragments, and un-escapes the string literals
back into a single `index.html`. Re-run it after any UI edit.

`server.py` serves that file and speaks the firmware's exact WebSocket protocol
on `/ws`:

| Message | Payload |
|---|---|
| Binary | 4-byte little-endian timestamp, then 768 × `int16` little-endian; temperature = value ÷ 10, in °C |
| Text | `{"type":"status","ambient":…,"maxTemp":…,"burners":[…],"alerts":[…],"recipe":{…}}` |

Frames go out at 4 Hz to match the MLX90640; status at 2 Hz. The scene is a
four-burner cooktop viewed from above — a stockpot pinned at boiling, a cast-iron
skillet climbing toward searing temperature, an empty burner, and a saucepan
holding a simmer. Burner states and alert types mirror the enums in
`firmware/include/stoveiq_types.h`.

## Seeding a configured kitchen

Burner names, the cookware library, calibration offsets, and past cook sessions
all live in `localStorage`, not on the device. A fresh browser profile shows an
unconfigured UI. To reproduce the committed screenshots, set these keys before
loading:

| Key | Contents |
|---|---|
| `siq_cal` | `[{r,c,rad,name}]` — burner zones in sensor coordinates |
| `siq_cookware` | `[{id,name,icon,material,notes,created}]` |
| `siq_burner_cookware` | `{burnerId: cookwareId}` |
| `siq_calib_offsets` | `{"<burnerId>_<cookwareId>": offsetC}` |
| `siq_sessions` | `[{id,burner_id,cookware_id,label,started_ms,ended,samples,events}]` |
| `siq_unit` | `"C"` or `"F"` |

`ended` must be consistent with `started_ms` — the session chart derives its time
axis from the difference, and an inconsistent pair renders as
"No samples in this window".

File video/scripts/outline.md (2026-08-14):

# Video Outline: I Built a $50 Thermal Cooking Coach (and it actually works)

## Target: Build/Demo, ~9 minutes, Makers + Hobbyist Cooks + Hackaday/DIY Community
## Tone: Casual maker energy. "Look what I built." Authentic, not overproduced.
## Narration: Mix of voiceover [VO] and live on-camera [LIVE]

---

## Chapter 1: The Problem (0:00 - 1:00)
### Summary
Open with a provocative hook that frames the gap between existing cooking tech (dumb timers, single-point probes) and what should exist (a stove that can see). Build frustration, then pivot to "what if?"
### Key Points
- Every cooking app on the planet is a glorified countdown timer
- Probe thermometers measure one point, in one dish, at a time
- Nobody is watching the whole stove surface -- until now
- Hook: "What if your stove could actually SEE what you're cooking?"
### Scenes: 3
### Visual Approach
Split-screen comparison: timer app UI vs. StoveIQ thermal heatmap. Quick cuts between frustrated cooking moments and the thermal camera reveal.

---

## Chapter 2: The Idea (1:00 - 2:00)
### Summary
Introduce the two core components (MLX90640 thermal camera + ESP32-S3 microcontroller), explain the cost, and land the open-source value proposition. This is the "aha" moment where the audience realizes how accessible this is.
### Key Points
- MLX90640: 24x32 pixels of infrared thermal data, 110-degree field of view, 4Hz
- ESP32-S3: WiFi + BLE, runs the entire system -- sensor read, cooking engine, web server
- Total cost: $50-95 depending on where you source parts
- 100% local -- no cloud, no subscription, no app store. Just a browser.
- Open source: MIT software, CERN-OHL-S hardware
### Scenes: 3
### Visual Approach
Clean product shots of the two boards. Animated overlay showing what each component does. Cost breakdown graphic.

---

## Chapter 3: The Build (2:00 - 4:15)
### Summary
Walk through the physical build from unboxing to first thermal image. This is the core maker content -- show how easy it is to replicate. Breadboard wiring, firmware flash, BLE provisioning, and the "money shot" of seeing the stove in thermal vision for the first time.
### Key Points
- BOM: 2 boards + 4 jumper wires + USB cable
- Wiring: VIN to 3V3, GND to GND, SDA to GPIO 1, SCL to GPIO 2
- Firmware flash with PlatformIO (one command)
- BLE provisioning with ESP BLE Prov app (PoP: stoveiq-setup)
- First thermal image on the web dashboard -- the money shot
- PVC pipe enclosure: split pipe, drill sensor window, snap together
### Scenes: 6
### Visual Approach
Overhead workbench camera for wiring. Screen capture for PlatformIO terminal. Phone screen recording for BLE provisioning. Dashboard reveal is the hero moment -- hold on the heatmap.

---

## Chapter 4: The Cooking Coach (4:15 - 6:30)
### Summary
Live cooking demo showing the full coaching experience. Open the dashboard on a phone, show the heatmap with real burners, calibrate burner zones, and run a recipe with thermal-aware coaching. This is the "it actually works" proof.
### Key Points
- Open stoveiq.local on phone while at the stove
- Live heatmap showing real burner temperatures
- Burner calibration: draw circles over each burner zone on the heatmap
- Start a recipe (pasta): thermal triggers detect boil, prompt for actions, run timers
- "It knows my water is boiling before I do"
- Progress bars, coaching messages, confirmation buttons
- Multiple burners tracked simultaneously
### Scenes: 5
### Visual Approach
Split-screen: phone dashboard on left, actual stove on right. Close-ups of the phone showing coaching messages. Wide shot of cooking with the phone propped on the counter. Genuine reactions.

---

## Chapter 5: The Recipe System (6:30 - 8:00)
### Summary
Explain how recipes work under the hood -- JSON state machines with thermal triggers. Show the community recipe model (GitHub PRs) and simulation mode for testing without cooking. Make the audience want to contribute.
### Key Points
- Recipes are JSON files with steps, triggers, and coaching messages
- 8 trigger types: target temp, boil, simmer, food_drop, timer, confirm, manual, temp_below
- 6 built-in recipes: rice, steak, pasta, eggs, potatoes, caramelized onions
- Community contribution via GitHub pull requests
- Simulation mode: test recipes with virtual thermal data, no cooking required
- Show a recipe JSON side-by-side with the dashboard running it
### Scenes: 4
### Visual Approach
Code editor showing recipe JSON with callout annotations. Screen capture of simulation mode. GitHub repo page showing the recipes directory. Side-by-side: JSON steps mapping to dashboard UI states.

---

## Chapter 6: What's Next + CTA (8:00 - 9:00)
### Summary
Point viewers to all the resources, tease upcoming features (PCB, more recipes), and issue a clear call to action: build one, contribute a recipe, join the community.
### Key Points
- Hackaday.io project page (build log, discussion)
- GitHub repo: firmware, recipes, hardware files
- PCB design coming (KiCad, open source) -- no more breadboard
- "Build one. Contribute a recipe. Let's make cooking apps obsolete."
- Subscribe to the channel for build updates
- Star the repo on GitHub
### Scenes: 3
### Visual Approach
Quick montage of the project links with QR codes. Teaser render of the PCB (if available). End card with subscribe button and GitHub link.

---

## Estimated Runtime: 9 minutes
## Total Chapters: 6
## Total Scenes: 24
## Estimated Word Count (narration): ~1,350 words at 150 WPM

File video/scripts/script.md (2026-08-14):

# Video Script: I Built a $100 Thermal Cooking Coach (and it actually works)

**Channel:** Vistter
**Target Runtime:** ~9 minutes (~1,350 words at 150 WPM)
**Narration Style:** [VO] = pre-recorded voiceover, [LIVE] = on-camera with talking points

---

# Chapter 1: The Problem (0:00 - 1:00)

## [SCENE 1: Cold Open / Hook - 0:00-0:15] [VO]

[VISUAL: Close-up of a phone showing a generic cooking timer app counting down. Camera pulls back to show a pot on a stove, steam rising, nothing interesting happening.]

NARRATION:
"Every cooking app on the planet is just a dumb timer. You tap start, you wait, it beeps. That's it. That's the whole thing."

[TRANSITION: Hard cut]

---

## [SCENE 2: The Frustration - 0:15-0:35] [VO]

[VISUAL: Quick montage -- (A) probe thermometer stuck in a steak, showing one number. (B) Someone checking a timer on their phone while something boils over on the stove behind them. (C) Hands awkwardly juggling a probe wire while trying to flip food.]

NARRATION:
"Probe thermometers? Great -- you get one temperature, in one dish, at one point. Meanwhile your other burner is about to smoke because you forgot about it. There's nothing watching the whole stove. Nobody's built that. Until now."

[TRANSITION: Smash cut to thermal heatmap]

---

## [SCENE 3: The Reveal - 0:35-1:00] [VO]

[VISUAL: Full-screen thermal heatmap of a real stove with two burners lit. Bright heat zones glow against the cool background. Hold for two seconds, then overlay the text.]

[TEXT OVERLAY: "What if your stove could actually SEE what you're cooking?"]

NARRATION:
"What if your stove could actually see what you're cooking? Not a timer. Not a probe. A thermal camera that watches your entire cooktop and coaches you through every step."

[VISUAL: Dashboard UI fades in over the heatmap -- burner cards showing temperatures, a recipe progress bar, a coaching message that says "Rolling boil!"]

"I built one. It cost me a hundred bucks. And it actually works."

[TEXT OVERLAY: Title card -- "I Built a $100 Thermal Cooking Coach"]
[MUSIC: Upbeat maker-style track fades in]

[TRANSITION: Crossfade, 1s]

---

# Chapter 2: The Idea (1:00 - 2:00)

## [SCENE 4: The Sensor - 1:00-1:20] [VO]

[VISUAL: Close-up of the MLX90640 breakout board on a white surface. Slow zoom in on the sensor window.]

NARRATION:
"This is the MLX90640. It's a twenty-four by thirty-two pixel infrared thermal array with a hundred-and-ten-degree field of view. Seven hundred and sixty-eight pixels of heat data, four times per second. It sees temperature, not light."

[TRANSITION: Cut]

---

## [SCENE 5: The Brain - 1:20-1:40] [VO]

[VISUAL: Close-up of the ESP32-S3 DevKit board. Animated arrows pointing to key features: WiFi antenna, USB-C, GPIO pins.]

NARRATION:
"And this is the brain -- an ESP32-S3. WiFi, Bluetooth, dual-core processor. It reads the sensor, runs the cooking engine, and serves a full web dashboard. No phone app needed. No cloud. You just open a browser."

[TRANSITION: Cut]

---

## [SCENE 6: The Pitch - 1:40-2:00] [VO]

[VISUAL: Both boards side by side. Animated price tags appear: "$75" over the sensor, "$16" over the ESP32, "$4" for wires and cable. Total: "$95" -- then slashes to "$50" with text "Chinese source modules from $25"]

NARRATION:
"Two boards. Four wires. About a hundred bucks from Adafruit. You can get it cheaper if you source the sensor module directly from AliExpress, but I paid full price and it was worth every penny. Open source -- MIT for the software, CERN Open Hardware for the board files. No cloud, no subscription, no app store. Forever."

[TEXT OVERLAY: "MIT Software | CERN-OHL-S Hardware | Zero Cloud"]

[TRANSITION: Crossfade, 1s]

---

# Chapter 3: The Build (2:00 - 4:15)

## [SCENE 7: The BOM - 2:00-2:15] [LIVE]

[VISUAL: Overhead shot of parts laid out on workbench: ESP32-S3 DevKit, MLX90640 breakout, 4 jumper wires, USB-C cable.]

TALKING POINTS:
- "Here's everything you need. Two boards, four jumper wires, a USB cable. That's the whole BOM."
- Hold up each part briefly
- Mention Adafruit part numbers (PID 5312, PID 4469)

[TRANSITION: Cut]

---

## [SCENE 8: Wiring - 2:15-3:00] [LIVE]

[VISUAL: Close-up overhead of breadboard. Hands connecting the four wires one at a time.]

TALKING POINTS:
- "Four wires. That's it."
- Walk through each connection: "VIN to three-point-three volts. Ground to ground. SDA to GPIO one. SCL to GPIO two."
- Show the completed wiring -- clean shot, pause so viewers can screenshot
- "If you can plug in a USB cable, you can build this."

[TEXT OVERLAY: Wiring diagram graphic overlay during the connections:
  ESP32-S3 --> MLX90640
  3V3 --> VIN
  GND --> GND
  GPIO 1 --> SDA
  GPIO 2 --> SCL]

[TRANSITION: Cut]

---

## [SCENE 9: Flash Firmware - 3:00-3:25] [VO + Screen Capture]

[VISUAL: Terminal screen capture showing PlatformIO build and upload.]

NARRATION:
"Firmware is built on ESP-IDF five-point-five with FreeRTOS. You flash it with PlatformIO -- clone the repo, cd into firmware, pio run dash-t upload. It compiles, it flashes, done."

[VISUAL: Terminal shows successful upload, device reboots]

"The device boots into AP mode -- it creates its own WiFi network called StoveIQ. Connect to that and open one-nine-two dot one-six-eight dot four dot one."

[TRANSITION: Cut]

---

## [SCENE 10: BLE Provisioning - 3:25-3:50] [LIVE + Screen Capture]

[VISUAL: Phone screen recording of the ESP BLE Prov app. Show scanning, connecting, entering PoP, selecting WiFi network.]

TALKING POINTS:
- "To get it on your home WiFi, use the ESP BLE Provisioning app."
- "Scan, connect to StoveIQ, enter the proof-of-possession code: stoveiq dash setup."
- "Pick your WiFi network, enter the password, and it connects."
- Show the dashboard now accessible at stoveiq.local

[TRANSITION: Cut]

---

## [SCENE 11: First Light - The Money Shot - 3:50-4:05] [LIVE]

[VISUAL: Phone or laptop browser showing the StoveIQ dashboard for the first time. Thermal heatmap is live, showing the stove surface. User turns on a burner -- the heatmap blooms with color in real time.]

TALKING POINTS:
- This is the moment. Let it breathe.
- "There it is. Real-time thermal imaging of my stove. From two boards and four wires."
- Turn on a burner while the camera is rolling -- show the heat appear live
- Genuine reaction encouraged

[TRANSITION: Cut]

---

## [SCENE 12: Enclosure - 4:05-4:15] [LIVE]

[VISUAL: Quick montage of PVC pipe enclosure build: (A) pipe cut in half, (B) hole drilled for sensor, (C) boards placed inside, (D) halves snapped together, (E) mounted under cabinet angled at stove.]

TALKING POINTS:
- "Enclosure is a dollar fifty of PVC pipe. Split it, drill a window for the sensor, snap it together."
- "Mount it under the cabinet with adhesive. Angle it down at the stove."
- "There are 3D-printable STLs in the repo too, but honestly, PVC works great."

[TRANSITION: Crossfade, 1s]

---

# Chapter 4: The Cooking Coach (4:15 - 6:30)

## [SCENE 13: Dashboard Tour - 4:15-4:45] [LIVE]

[VISUAL: Phone propped on counter showing the dashboard. Camera alternates between the phone screen and the actual stove.]

TALKING POINTS:
- "Open stoveiq dot local on your phone. This is the cooking coach."
- Walk through the UI: heatmap at the top, burner cards below showing per-burner temps
- Show the settings gear icon -- C/F toggle, simulation mode
- "Everything runs on the ESP32. No server, no cloud, no internet required."

[TRANSITION: Cut]

---

## [SCENE 14: Burner Calibration - 4:45-5:15] [LIVE]

[VISUAL: Phone screen showing calibration mode. User taps on heatmap to place burner zones, drags to position, uses +/- buttons to resize circles.]

TALKING POINTS:
- "First thing you do is calibrate your burners. Tap the gear, tap Calibrate."
- "Tap on the heatmap where each burner is. Drag to position. Plus and minus to resize."
- "It saves to the device -- you only do this once."
- Show all four burners calibrated -- the dashboard now labels them Burner 1, 2, 3, 4

[TRANSITION: Cut]

---

## [SCENE 15: Live Recipe Demo - 5:15-6:10] [LIVE]

[VISUAL: Full cooking sequence with the dashboard visible. This is the centerpiece demo. Phone on counter, pot on stove, camera captures both.]

TALKING POINTS:
- "Let's cook pasta. Tap Recipes, tap Pasta."
- Show step 1: "Fill pot with water, set to high" -- coaching message says "Heating up..."
- Show the temperature climbing on the burner card in real time
- Step 2: "Waiting for rolling boil..." -- the thermal camera detects boil at ~100C
- Coaching message: "Rolling boil!" with an audio chime
- "It knew my water was boiling before I did. I was in the other room."
- Step 3: "Add pasta and stir" -- tap Confirm
- Step 4: Timer starts -- 8 minutes, progress bar filling
- Show coaching message: "Check -- al dente?"
- "That's it. Every step told me what was happening on the stove. Not a guess. Not a timer. The camera SAW the boil."

[TRANSITION: Cut]

---

## [SCENE 16: Multiple Burners - 6:10-6:20] [LIVE]

[VISUAL: Dashboard showing two or three active burners simultaneously, each with independent temperature tracking.]

TALKING POINTS:
- "And it tracks all four burners independently. Two pots going? No problem."
- "Each burner has its own temperature, state, and trend."

[TRANSITION: Cut]

---

## [SCENE 17: The Comparison - 6:20-6:30] [VO]

[VISUAL: Side-by-side split screen. Left: generic timer app showing "8:00" counting down. Right: StoveIQ dashboard showing thermal heatmap, burner cards with live temps, recipe progress bar, coaching message "Rolling boil!"]

NARRATION:
"This is what a timer app shows you. And this is what StoveIQ shows you. One is guessing. The other one is watching."

[TRANSITION: Crossfade, 1s]

---

# Chapter 5: The Recipe System (6:30 - 8:00)

## [SCENE 18: How Recipes Work - 6:30-7:10] [VO + Screen Capture]

[VISUAL: Code editor (VS Code) showing the pasta recipe JSON file. Animated callouts highlight key fields as they're mentioned.]

NARRATION:
"Recipes are JSON state machines. Each step has a description, a trigger, and a coaching message. The triggers are thermal -- boil means the camera detected a rolling boil at a hundred degrees. Target means the burner hit a specific temperature. Food-drop means a sudden temperature drop when you put cold food in a hot pan."

[VISUAL: Animated diagram showing the step flow: Step 1 (target 50C) --> Step 2 (boil) --> Step 3 (confirm) --> Step 4 (timer 8 min)]

"The seared steak recipe is my favorite. It watches the pan climb to two-thirty Celsius, tells you the pan is screaming hot, you drop the steak, and it starts a three-minute sear timer. Then it says -- and I quote -- FLIP NOW."

[TRANSITION: Cut]

---

## [SCENE 19: The Recipe Library - 7:10-7:30] [VO + Screen Capture]

[VISUAL: GitHub repo page showing the /recipes directory. Click into the category folders -- basics, proteins, vegetables, sauces.]

NARRATION:
"Six recipes built in: white rice, pasta, fried eggs, boiled potatoes, caramelized onions, seared steak. But the real play is the community. Recipes live in a GitHub repo. You fork it, write a JSON file, test it in simulation mode, and submit a pull request."

[VISUAL: Show the PR template briefly]

"Every recipe gets tuned with real thermal data. Gas heats differently than induction -- the recipes know that."

[TRANSITION: Cut]

---

## [SCENE 20: Simulation Mode - 7:30-7:50] [LIVE + Screen Capture]

[VISUAL: Dashboard in simulation mode. Temperature slider being dragged to simulate heating. Recipe steps advancing as virtual temperatures hit triggers.]

TALKING POINTS:
- "And if you don't want to actually cook to test a recipe, there's simulation mode."
- Show the simulation slider and preset buttons
- Drag temperature up -- show recipe steps advancing
- "You can develop and test recipes without turning on your stove."

[TRANSITION: Cut]

---

## [SCENE 21: Recipe JSON Close-Up - 7:50-8:00] [VO + Screen Capture]

[VISUAL: Split screen -- JSON on the left, dashboard running that recipe on the right. As each step activates in the dashboard, the corresponding JSON step highlights on the left.]

NARRATION:
"Five fields. That's a recipe. If you can write JSON, you can teach a stove to cook."

[TEXT OVERLAY: "Five fields. One recipe. Fork the repo."]

[TRANSITION: Crossfade, 1s]

---

# Chapter 6: What's Next + CTA (8:00 - 9:00)

## [SCENE 22: Resources - 8:00-8:25] [VO]

[VISUAL: Quick montage of project links with QR codes overlaid: (A) Hackaday.io project page, (B) GitHub repo main page, (C) Recipes directory]

NARRATION:
"Everything is on GitHub -- firmware, recipes, hardware files, enclosure models. The Hackaday dot io project page has the full build log. Links are in the description."

[TEXT OVERLAY: QR codes for GitHub repo and Hackaday.io page]

[TRANSITION: Cut]

---

## [SCENE 23: What's Coming - 8:25-8:45] [VO]

[VISUAL: Teaser images -- (A) KiCad PCB layout render (if available), (B) 3D enclosure render, (C) GitHub Issues page showing planned features]

NARRATION:
"Next up -- a proper PCB. No more breadboard. Open-source KiCad files so you can order boards from JLCPCB or PCBWay. And more recipes -- I want a hundred community-contributed recipes by the end of the year."

[TRANSITION: Cut]

---

## [SCENE 24: Call to Action / End Card - 8:45-9:00] [LIVE]

[VISUAL: On-camera, holding the device. Genuine, direct to camera.]

TALKING POINTS:
- "Build one. It's two boards and four wires."
- "Contribute a recipe. Fork the repo."
- "Let's make cooking apps obsolete."
- "Subscribe for the build series -- next video is a deep dive on the thermal imaging pipeline."
- "Star the repo on GitHub. Link in the description."

[TEXT OVERLAY: End card with subscribe button, GitHub link, Hackaday.io link]
[MUSIC: Fade out]

---

## Production Notes

### Word Count Summary
- Voiceover narration: ~1,050 words
- Estimated VO runtime at 150 WPM: ~7:00
- Live on-camera segments: ~2:00 of talking points (not scripted word-for-word)
- Total estimated runtime: ~9:00

### Music
- Upbeat, lo-fi maker/workshop vibe
- Fade in at title card (0:50), maintain under VO at ~12% volume
- Fade out at end card (8:55)

### B-Roll Needed
- Generic cooking timer app (stock or screen record)
- Probe thermometer in food (film or stock)
- Boiling pot (film)
- Workbench overhead shots (film)
- Terminal/PlatformIO screen capture (record)
- BLE provisioning phone recording (record)
- Full cooking demo footage with dashboard visible (film)
- GitHub repo screen capture (record)

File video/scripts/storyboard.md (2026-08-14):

# Storyboard: I Built a $100 Thermal Cooking Coach (and it actually works)

---

# Chapter 1: The Problem (0:00 - 1:00)
> Hook the viewer by exposing the gap between what cooking apps do (timers) and what they should do (see). Smash cut to the thermal heatmap reveal.

## Scene 1: Cold Open / Hook
- **Duration:** 15 seconds
- **Narration type:** [VO]
- **Image source:** Live footage + screen capture
- **Shot list:**
  1. Close-up of phone showing a generic timer app counting down (5s)
  2. Camera pulls back to reveal a pot on the stove, steam rising, nothing happening (5s)
  3. Quick cut to black (0.5s)
- **Image orientation:** landscape
- **Text overlay:** None
- **Motion:** static (phone screen), gentle pull-back (stove reveal)
- **Audio:** Narration + ambient kitchen sounds, no music yet
- **Transition out:** Hard cut

## Scene 2: The Frustration
- **Duration:** 20 seconds
- **Narration type:** [VO]
- **Image source:** Live footage (film) or stock
- **Shot list:**
  1. Probe thermometer stuck in a steak, single number on display (4s)
  2. Someone checking timer on phone while pot boils over behind them (5s)
  3. Hands juggling probe wire while flipping food (4s)
  4. Wide shot of messy stovetop, multiple burners, no tech helping (7s)
- **Image orientation:** landscape
- **Text overlay:** None
- **Motion:** quick cuts, handheld feel
- **Audio:** Narration, ambient kitchen, slight tension music sting at boilover
- **Transition out:** Smash cut to Scene 3

## Scene 3: The Reveal
- **Duration:** 25 seconds
- **Narration type:** [VO]
- **Image source:** Screen capture (dashboard heatmap) + AI-generated title card
- **Shot list:**
  1. Full-screen thermal heatmap of stove with two burners lit -- hold 3s
  2. Text overlay fades in: "What if your stove could actually SEE what you're cooking?" (4s)
  3. Dashboard UI fades in over heatmap: burner cards, recipe progress, "Rolling boil!" message (8s)
  4. Title card: "I Built a $100 Thermal Cooking Coach" (5s)
- **Image orientation:** landscape
- **Text overlay:** Hook question, then title
- **Motion:** static (heatmap hold), gentle-zoom (dashboard), static (title card)
- **Audio:** Narration. Music fades in on title card -- upbeat maker track
- **Transition out:** Crossfade 1s

---

# Chapter 2: The Idea (1:00 - 2:00)
> Introduce the two core components and land the cost + open-source value proposition. The audience should think: "I could build that."

## Scene 4: The Sensor
- **Duration:** 20 seconds
- **Narration type:** [VO]
- **Image source:** Live footage (product shot of MLX90640 breakout)
- **Shot list:**
  1. Clean close-up of MLX90640 breakout board on white/dark surface (8s)
  2. Slow zoom into the sensor window (gold square) (6s)
  3. Animated overlay: "24x32 IR pixels | 110deg FoV | 4Hz" (6s)
- **Image orientation:** landscape
- **Text overlay:** Sensor specs animated in
- **Motion:** slow zoom, then static for specs overlay
- **Audio:** Narration + background music at 12%
- **Transition out:** Cut

## Scene 5: The Brain
- **Duration:** 20 seconds
- **Narration type:** [VO]
- **Image source:** Live footage (product shot of ESP32-S3 DevKit)
- **Shot list:**
  1. Close-up of ESP32-S3 DevKit board (6s)
  2. Animated arrows pointing to WiFi antenna, USB-C, GPIO pins (8s)
  3. Text: "Sensor + Cooking Engine + Web Server = One Chip" (6s)
- **Image orientation:** landscape
- **Text overlay:** Feature callouts, then summary text
- **Motion:** gentle-zoom with animated overlays
- **Audio:** Narration + background music at 12%
- **Transition out:** Cut

## Scene 6: The Pitch
- **Duration:** 20 seconds
- **Narration type:** [VO]
- **Image source:** Live footage (both boards together) + graphic overlay
- **Shot list:**
  1. Both boards side by side on surface (5s)
  2. Animated price breakdown: "$75 sensor + $16 ESP32 + $4 wires = $95" (5s)
  3. Price slashes to "$50 with Chinese-source modules" (3s)
  4. License badges: "MIT Software | CERN-OHL-S Hardware | Zero Cloud" (7s)
- **Image orientation:** landscape
- **Text overlay:** Price breakdown, license badges
- **Motion:** static with animated overlays
- **Audio:** Narration + background music at 12%
- **Transition out:** Crossfade 1s

---

# Chapter 3: The Build (2:00 - 4:15)
> Core maker content. Show the full build from parts on the table to first thermal image. Emphasis on accessibility -- "if you can plug in a USB cable, you can build this."

## Scene 7: The BOM
- **Duration:** 15 seconds
- **Narration type:** [LIVE]
- **Image source:** Live footage (overhead workbench)
- **Shot list:**
  1. Overhead shot: all parts laid out on workbench (8s)
  2. Hands picking up each part briefly (7s)
- **Image orientation:** landscape
- **Text overlay:** Part names + Adafruit PIDs as items are picked up
- **Motion:** overhead static, handheld when picking up parts
- **Audio:** Live audio + background music at 10%
- **Transition out:** Cut

## Scene 8: Wiring
- **Duration:** 45 seconds
- **Narration type:** [LIVE]
- **Image source:** Live footage (overhead close-up of wiring)
- **Shot list:**
  1. Close-up of empty breadboard with both boards placed (5s)
  2. Connecting wire 1: VIN to 3V3 (8s)
  3. Connecting wire 2: GND to GND (6s)
  4. Connecting wire 3: SDA to GPIO 1 (8s)
  5. Connecting wire 4: SCL to GPIO 2 (8s)
  6. Pull back to show completed wiring -- hold for screenshot (10s)
- **Image orientation:** landscape
- **Text overlay:** Wiring diagram graphic overlay during connections
- **Motion:** overhead static, slow deliberate movements
- **Audio:** Live audio + background music at 10%
- **Transition out:** Cut

## Scene 9: Flash Firmware
- **Duration:** 25 seconds
- **Narration type:** [VO]
- **Image source:** Screen capture (terminal)
- **Shot list:**
  1. Terminal: `git clone` command (4s)
  2. Terminal: `cd firmware && pio run -t upload` (6s)
  3. Compile output scrolling (sped up 4x) (8s)
  4. Upload complete, device reboots (4s)
  5. Brief shot of serial monitor showing boot messages (3s)
- **Image orientation:** landscape
- **Text overlay:** Command text highlighted/enlarged
- **Motion:** static (screen capture)
- **Audio:** Narration + background music at 12%
- **Transition out:** Cut

## Scene 10: BLE Provisioning
- **Duration:** 25 seconds
- **Narration type:** [LIVE]
- **Image source:** Phone screen recording + live footage
- **Shot list:**
  1. Phone showing ESP BLE Prov app -- scanning (5s)
  2. Connecting to "StoveIQ" device (3s)
  3. Entering PoP: stoveiq-setup (5s)
  4. WiFi network selection (4s)
  5. "Connected!" confirmation (3s)
  6. Brief cut to phone browser opening stoveiq.local (5s)
- **Image orientation:** portrait (phone recording) -- will need pillarbox or picture-in-picture
- **Text overlay:** PoP code "stoveiq-setup" highlighted
- **Motion:** pillarbox for phone recording, or PIP over workbench shot
- **Audio:** Live audio + background music at 10%
- **Transition out:** Cut

## Scene 11: First Light -- The Money Shot
- **Duration:** 15 seconds
- **Narration type:** [LIVE]
- **Image source:** Live footage (phone/laptop showing dashboard + stove)
- **Shot list:**
  1. Dashboard loads -- heatmap appears showing room-temperature stove (3s)
  2. Hand reaches to stove, turns on a burner (3s)
  3. Heat bloom appears on the heatmap in real time (5s) -- HOLD THIS SHOT
  4. Reaction shot (4s)
- **Image orientation:** landscape
- **Text overlay:** None -- let the visual speak
- **Motion:** static/handheld
- **Audio:** Live audio, genuine reaction, music dips slightly for the reveal
- **Transition out:** Cut

## Scene 12: Enclosure
- **Duration:** 10 seconds
- **Narration type:** [LIVE]
- **Image source:** Live footage (quick build montage)
- **Shot list:**
  1. PVC pipe cut in half (2s)
  2. Hole drilled for sensor (2s)
  3. Boards placed inside (2s)
  4. Halves snapped together (2s)
  5. Mounted under cabinet pointing at stove (2s)
- **Image orientation:** landscape
- **Text overlay:** None
- **Motion:** quick cuts, montage pace
- **Audio:** Live audio + music slightly louder for montage energy
- **Transition out:** Crossfade 1s

---

# Chapter 4: The Cooking Coach (4:15 - 6:30)
> This is the proof. Live cooking demo showing the thermal-aware coaching system working in a real kitchen. Split attention between the phone dashboard and the actual stove.

## Scene 13: Dashboard Tour
- **Duration:** 30 seconds
- **Narration type:** [LIVE]
- **Image source:** Live footage (phone on counter + stove in background)
- **Shot list:**
  1. Wide shot: phone propped on counter, stove visible behind (5s)
  2. Close-up of phone: heatmap at top of dashboard (8s)
  3. Close-up of phone: burner cards below showing temps (8s)
  4. Tap settings gear: show C/F toggle, simulation mode (5s)
  5. Pull back to wide shot (4s)
- **Image orientation:** landscape (wide), portrait phone inserts via PIP
- **Text overlay:** UI element labels if needed for clarity
- **Motion:** mix of static wide and handheld close-ups
- **Audio:** Live audio + background music at 10%
- **Transition out:** Cut

## Scene 14: Burner Calibration
- **Duration:** 30 seconds
- **Narration type:** [LIVE]
- **Image source:** Phone screen recording + live footage
- **Shot list:**
  1. Tap gear icon, tap "Calibrate Burners" (3s)
  2. Heatmap in calibration mode -- tap to place first burner zone (5s)
  3. Drag circle to position over burner (4s)
  4. +/- buttons to resize (3s)
  5. Repeat quickly for remaining burners (8s)
  6. All four burners calibrated -- dashboard shows labeled burner cards (7s)
- **Image orientation:** portrait (phone recording) via PIP over kitchen wide shot
- **Text overlay:** "Calibrate once. Cook forever." at end
- **Motion:** pillarbox/PIP for phone, static for kitchen
- **Audio:** Live audio + background music at 10%
- **Transition out:** Cut

## Scene 15: Live Recipe Demo
- **Duration:** 55 seconds
- **Narration type:** [LIVE]
- **Image source:** Live footage (split view: phone dashboard + actual stove)
- **Shot list:**
  1. Tap Recipes on dashboard, tap Pasta (5s)
  2. Step 1 active: "Fill pot with water, set to high" -- water going into pot (8s)
  3. Dashboard: temperature climbing on burner card (6s)
  4. Step 2: "Waiting for rolling boil..." -- pot starting to bubble (8s)
  5. Dashboard: boil detected! Coaching message: "Rolling boil!" with chime (5s)
  6. Reaction: "It knew before I did. I was in the other room." (4s)
  7. Step 3: "Add pasta and stir" -- pasta going in, tap Confirm (6s)
  8. Step 4: Timer running, progress bar filling (5s)
  9. Timer complete: "Check -- al dente?" (4s)
  10. Drain and serve -- quick montage (4s)
- **Image orientation:** landscape (split screen or alternating)
- **Text overlay:** Recipe step name in corner during each step
- **Motion:** handheld, documentary feel, genuine cooking
- **Audio:** Live audio (sizzling, water, chime sounds), music at 8%
- **Transition out:** Cut

## Scene 16: Multiple Burners
- **Duration:** 10 seconds
- **Narration type:** [LIVE]
- **Image source:** Live footage (dashboard showing multiple active burners)
- **Shot list:**
  1. Dashboard showing 2-3 burners active with independent temps (5s)
  2. Quick pan across actual stove with multiple pots/pans (5s)
- **Image orientation:** landscape
- **Text overlay:** None
- **Motion:** static dashboard, handheld pan across stove
- **Audio:** Live audio + background music at 10%
- **Transition out:** Cut

## Scene 17: The Comparison
- **Duration:** 10 seconds
- **Narration type:** [VO]
- **Image source:** Screen capture (side-by-side comparison graphic)
- **Shot list:**
  1. Split screen: LEFT = generic timer "8:00" counting down. RIGHT = StoveIQ dashboard with heatmap, burner cards, recipe progress, "Rolling boil!" message (10s)
- **Image orientation:** landscape
- **Text overlay:** LEFT: "Timer App" / RIGHT: "StoveIQ"
- **Motion:** static
- **Audio:** Narration + background music at 12%
- **Transition out:** Crossfade 1s

---

# Chapter 5: The Recipe System (6:30 - 8:00)
> Pull back the curtain on how recipes work. Make the audience want to contribute their own.

## Scene 18: How Recipes Work
- **Duration:** 40 seconds
- **Narration type:** [VO]
- **Image source:** Screen capture (VS Code + animated diagram)
- **Shot list:**
  1. VS Code showing pasta.json with syntax highlighting (10s)
  2. Animated callouts highlighting: "desc", "trigger", "coach_msg" fields (10s)
  3. Animated flow diagram: Step 1 (target 50C) -> Step 2 (boil) -> Step 3 (confirm) -> Step 4 (timer 8min) (10s)
  4. Quick cut to seared-steak.json -- highlight "PAN IS SCREAMING HOT!" and "FLIP NOW!" coach messages (10s)
- **Image orientation:** landscape
- **Text overlay:** Field labels as callouts
- **Motion:** static code, animated overlays
- **Audio:** Narration + background music at 12%
- **Transition out:** Cut

## Scene 19: The Recipe Library
- **Duration:** 20 seconds
- **Narration type:** [VO]
- **Image source:** Screen capture (GitHub)
- **Shot list:**
  1. GitHub repo /recipes directory listing (5s)
  2. Click into /basics -- show 4 recipe files (4s)
  3. Click into /proteins -- show seared-steak.json (3s)
  4. PR template shown briefly (4s)
  5. Quick shot of /community folder (empty -- "yours goes here") (4s)
- **Image orientation:** landscape
- **Text overlay:** "Fork. Write JSON. Submit PR."
- **Motion:** static (screen capture with cursor movement)
- **Audio:** Narration + background music at 12%
- **Transition out:** Cut

## Scene 20: Simulation Mode
- **Duration:** 20 seconds
- **Narration type:** [LIVE]
- **Image source:** Phone screen recording + live footage
- **Shot list:**
  1. Dashboard settings: toggle Simulation Mode on (4s)
  2. Temperature slider appears -- drag it up (4s)
  3. Recipe steps advancing as virtual temp hits triggers (8s)
  4. "Boil detected!" in simulation -- no actual cooking (4s)
- **Image orientation:** landscape or PIP
- **Text overlay:** "Test recipes without cooking"
- **Motion:** static/screen capture
- **Audio:** Live audio explaining + background music at 10%
- **Transition out:** Cut

## Scene 21: Recipe JSON Close-Up
- **Duration:** 10 seconds
- **Narration type:** [VO]
- **Image source:** Screen capture (split screen)
- **Shot list:**
  1. LEFT: JSON recipe file. RIGHT: Dashboard running that recipe. As each step activates in the dashboard, the corresponding JSON step highlights on the left. (10s)
- **Image orientation:** landscape
- **Text overlay:** "Five fields. One recipe. Fork the repo."
- **Motion:** static with highlight animations
- **Audio:** Narration + background music at 12%
- **Transition out:** Crossfade 1s

---

# Chapter 6: What's Next + CTA (8:00 - 9:00)
> Point to resources, tease the roadmap, issue a direct call to action.

## Scene 22: Resources
- **Duration:** 25 seconds
- **Narration type:** [VO]
- **Image source:** Screen capture + AI-generated QR graphics
- **Shot list:**
  1. Hackaday.io project page (5s)
  2. GitHub repo main page with star count visible (5s)
  3. Recipes directory (3s)
  4. QR codes for both links overlaid (7s)
  5. Description text: "Links in the description" (5s)
- **Image orientation:** landscape
- **Text overlay:** URLs + QR codes
- **Motion:** static (screen captures)
- **Audio:** Narration + background music at 12%
- **Transition out:** Cut

## Scene 23: What's Coming
- **Duration:** 20 seconds
- **Narration type:** [VO]
- **Image source:** Screen capture (KiCad) + AI-generated PCB render
- **Shot list:**
  1. KiCad PCB layout or 3D render of the custom board (8s)
  2. Text: "No more breadboard." (3s)
  3. GitHub Issues page showing planned features (5s)
  4. Text: "100 community recipes by end of 2026" (4s)
- **Image orientation:** landscape
- **Text overlay:** Feature teasers
- **Motion:** gentle-zoom on PCB render, static for GitHub
- **Audio:** Narration + background music at 12%
- **Transition out:** Cut

## Scene 24: Call to Action / End Card
- **Duration:** 15 seconds
- **Narration type:** [LIVE]
- **Image source:** Live footage (on-camera, holding device)
- **Shot list:**
  1. Direct to camera, holding the assembled device (10s)
  2. End card with subscribe button, GitHub link, Hackaday link (5s)
- **Image orientation:** landscape
- **Text overlay:** End card elements -- subscribe, GitHub star, Hackaday.io
- **Motion:** static (on-camera), static (end card)
- **Audio:** Live audio, music fade out at 8:55
- **Transition out:** Fade to black

---

# Asset Summary

## By Source Type

| Source Type | Count | Notes |
|---|---|---|
| Live footage (film) | 14 scenes | Workbench, cooking demo, on-camera |
| Screen capture (record) | 5 scenes | Terminal, GitHub, VS Code, dashboard |
| AI-generated graphics | 4 assets | Title card, QR graphic, PCB render, comparison graphic |
| Title card | 1 asset | Video title at 0:50 |
| **Total unique scenes** | **24** | |

## Graphics/Overlays Needed

1. Wiring diagram overlay (Scene 8)
2. Price breakdown animation (Scene 6)
3. License badge graphic (Scene 6)
4. Sensor specs overlay (Scene 4)
5. ESP32 feature callout arrows (Scene 5)
6. Recipe flow diagram animation (Scene 18)
7. Side-by-side comparison graphic (Scene 17)
8. QR codes for GitHub + Hackaday (Scene 22)
9. End card template (Scene 24)

## Screen Captures Needed

1. Generic timer app (Scene 1)
2. PlatformIO terminal -- build + upload (Scene 9)
3. ESP BLE Prov app -- provisioning flow (Scene 10)
4. VS Code -- pasta.json and seared-steak.json (Scene 18)
5. GitHub -- /recipes directory, PR template (Scene 19)
6. Dashboard -- simulation mode (Scene 20)
7. Dashboard -- recipe running with JSON side-by-side (Scene 21)
8. Hackaday.io project page (Scene 22)
9. GitHub repo main page (Scene 22)
10. KiCad PCB layout or 3D render (Scene 23)

## Live Footage Shot List

1. Phone showing timer app + pot on stove (Scene 1)
2. Probe thermometer in steak (Scene 2)
3. Boilover moment (Scene 2)
4. Parts laid out on workbench (Scene 7)
5. Breadboard wiring -- 4 connections (Scene 8)
6. Phone BLE provisioning (Scene 10)
7. First thermal image + burner turn-on (Scene 11)
8. PVC pipe enclosure build montage (Scene 12)
9. Dashboard tour on phone (Scene 13)
10. Burner calibration on phone (Scene 14)
11. Full pasta cooking demo with dashboard visible (Scene 15)
12. Multiple burners active (Scene 16)
13. Simulation mode demo (Scene 20)
14. On-camera CTA, holding device (Scene 24)

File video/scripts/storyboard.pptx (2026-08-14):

## I Built a $50 Thermal Cooking Coach (and it actually works)

Build/Demo Video Storyboard
Vistter Channel | ~9 minutes | April 2026

## Chapter Overview

- Chapter 1: The Problem (0:00 - 1:00) -- 3 scenes
- Chapter 2: The Idea (1:00 - 2:00) -- 3 scenes
- Chapter 3: The Build (2:00 - 4:15) -- 6 scenes
- Chapter 4: The Cooking Coach (4:15 - 6:30) -- 5 scenes
- Chapter 5: The Recipe System (6:30 - 8:00) -- 4 scenes
- Chapter 6: What's Next + CTA (8:00 - 9:00) -- 3 scenes
- Total: 6 chapters, 24 scenes, ~9 minutes
- Narration: Mix of voiceover [VO] and live on-camera [LIVE]
- Audience: Makers, hobbyist cooks, Hackaday/DIY community

## Chapter 1: The Problem

- 0:00 - 1:00 | 3 scenes
- Hook the viewer by exposing the gap between dumb timers and what should exist -- a stove that can see.

## Scene 1: Cold Open / Hook (0:00 - 0:15)

- NARRATION: "Every cooking app on the planet is just a dumb timer. You tap start, you wait, it beeps. That's it."
- VISUAL: Close-up of phone showing timer app counting down, camera pulls back to reveal pot on stove
- IMAGE: Live footage + screen capture
- MOTION: static (phone), gentle pull-back (stove)
- TRANSITION: Hard cut
- TYPE: [VO]

## Scene 2: The Frustration (0:15 - 0:35)

- NARRATION: "Probe thermometers? Great -- you get one temperature, in one dish, at one point. Meanwhile your other burner is about to smoke..."
- VISUAL: Montage -- probe in steak, boilover while checking phone, juggling probe wire
- IMAGE: Live footage or stock
- MOTION: Quick cuts, handheld feel
- TRANSITION: Smash cut to heatmap
- TYPE: [VO]

## Scene 3: The Reveal (0:35 - 1:00)

- NARRATION: "What if your stove could actually see what you're cooking? I built one. It cost me fifty bucks. And it actually works."
- VISUAL: Full-screen thermal heatmap (2 burners lit), dashboard UI fades in, then title card
- TEXT: "What if your stove could actually SEE what you're cooking?"
- IMAGE: Screen capture (dashboard) + AI-generated title card
- MOTION: static heatmap hold, gentle-zoom on dashboard
- TRANSITION: Crossfade 1s
- TYPE: [VO] | MUSIC fades in here

## Chapter 2: The Idea

- 1:00 - 2:00 | 3 scenes
- Introduce the two core components and land the "$50, open source, no cloud" value proposition.

## Scene 4: The Sensor (1:00 - 1:20)

- NARRATION: "This is the MLX90640. 24 by 32 pixels of infrared thermal data, 110-degree field of view, 4Hz. It sees temperature, not light."
- VISUAL: Close-up of MLX90640 breakout, slow zoom into sensor window, specs overlay
- IMAGE: Live footage (product shot)
- MOTION: slow zoom + animated overlay
- TRANSITION: Cut
- TYPE: [VO]

## Scene 5: The Brain (1:20 - 1:40)

- NARRATION: "The brain -- an ESP32-S3. WiFi, Bluetooth, dual-core processor. It reads the sensor, runs the cooking engine, and serves a full web dashboard."
- VISUAL: Close-up of ESP32-S3 DevKit with animated feature callout arrows
- IMAGE: Live footage (product shot)
- TEXT: "Sensor + Cooking Engine + Web Server = One Chip"
- MOTION: gentle-zoom with animated overlays
- TRANSITION: Cut
- TYPE: [VO]

## Scene 6: The Pitch (1:40 - 2:00)

- NARRATION: "Two boards. Four wires. $95 from Adafruit, or $50 with Chinese-source modules. Open source. No cloud, no subscription. Forever."
- VISUAL: Both boards side by side, animated price breakdown, license badges
- IMAGE: Live footage + graphic overlay
- TEXT: "MIT Software | CERN-OHL-S Hardware | Zero Cloud"
- MOTION: static with animated overlays
- TRANSITION: Crossfade 1s
- TYPE: [VO]

## Chapter 3: The Build

- 2:00 - 4:15 | 6 scenes | MOSTLY LIVE
- Core maker content. From parts on the table to first thermal image. "If you can plug in a USB cable, you can build this."

## Scene 7: The BOM (2:00 - 2:15)

- TALKING POINTS: "Here's everything you need. Two boards, four jumper wires, a USB cable."
- VISUAL: Overhead shot of parts on workbench, hands picking up each part
- IMAGE: Live footage (overhead workbench camera)
- TEXT: Part names + Adafruit PIDs as items are picked up
- MOTION: overhead static, handheld pickup
- TRANSITION: Cut
- TYPE: [LIVE] -- 15 seconds

## Scene 8: Wiring (2:15 - 3:00)

- TALKING POINTS: "Four wires. VIN to 3.3V. GND to GND. SDA to GPIO 1. SCL to GPIO 2. If you can plug in a USB cable, you can build this."
- VISUAL: Close-up overhead of breadboard, connecting one wire at a time, hold on completed wiring
- IMAGE: Live footage (overhead close-up)
- TEXT: Wiring diagram graphic overlay during connections
- MOTION: overhead static, slow deliberate movements
- TRANSITION: Cut
- TYPE: [LIVE] -- 45 seconds

## Scene 9: Flash Firmware (3:00 - 3:25)

- NARRATION: "Firmware is ESP-IDF 5.5 with FreeRTOS. Clone the repo, cd firmware, pio run -t upload. It compiles, flashes, done."
- VISUAL: Terminal showing git clone, PlatformIO build (sped up 4x), successful upload
- IMAGE: Screen capture (terminal)
- MOTION: static
- TRANSITION: Cut
- TYPE: [VO] -- 25 seconds

## Scene 10: BLE Provisioning (3:25 - 3:50)

- TALKING POINTS: "ESP BLE Provisioning app. Scan, connect to StoveIQ, PoP code: stoveiq-setup. Pick your WiFi. Connected."
- VISUAL: Phone screen recording of BLE prov app flow, then browser opening stoveiq.local
- IMAGE: Phone screen recording (portrait) + live footage
- TEXT: PoP code "stoveiq-setup" highlighted
- MOTION: pillarbox for phone recording, or PIP over workbench
- TRANSITION: Cut
- TYPE: [LIVE] -- 25 seconds

## Scene 11: First Light -- THE MONEY SHOT (3:50 - 4:05)

- TALKING POINTS: "There it is. Real-time thermal imaging of my stove. From two boards and four wires."
- VISUAL: Dashboard loads with heatmap. User turns on burner -- heat bloom appears LIVE. Hold this shot. Genuine reaction.
- IMAGE: Live footage (phone/laptop + stove)
- MOTION: static/handheld -- let the visual speak
- TRANSITION: Cut
- TYPE: [LIVE] -- 15 seconds -- HERO MOMENT
- *** THIS IS THE THUMBNAIL MOMENT ***

## Scene 12: Enclosure (4:05 - 4:15)

- TALKING POINTS: "Enclosure is $1.50 of PVC pipe. Split it, drill a window, snap it together. Mount under the cabinet."
- VISUAL: Quick montage: pipe cut, hole drilled, boards in, halves snapped, mounted under cabinet
- IMAGE: Live footage (montage)
- MOTION: quick cuts, montage pace
- TRANSITION: Crossfade 1s
- TYPE: [LIVE] -- 10 seconds

## Chapter 4: The Cooking Coach

- 4:15 - 6:30 | 5 scenes | MOSTLY LIVE
- This is the proof. Live cooking demo showing the thermal-aware coaching system working in a real kitchen.

## Scene 13: Dashboard Tour (4:15 - 4:45)

- TALKING POINTS: "Open stoveiq.local on your phone. Heatmap at top, burner cards below, settings gear for C/F toggle. Everything runs on the ESP32."
- VISUAL: Phone propped on counter, stove behind. Close-ups of heatmap, burner cards, settings.
- IMAGE: Live footage (phone on counter + stove)
- MOTION: mix of static wide and handheld close-ups
- TRANSITION: Cut
- TYPE: [LIVE] -- 30 seconds

## Scene 14: Burner Calibration (4:45 - 5:15)

- TALKING POINTS: "Tap Calibrate. Tap on the heatmap where each burner is. Drag to position. Plus/minus to resize. You only do this once."
- VISUAL: Phone showing calibration mode -- tap, drag, resize circles over burner zones
- IMAGE: Phone screen recording (PIP) + live footage
- TEXT: "Calibrate once. Cook forever."
- MOTION: pillarbox/PIP for phone, static for kitchen
- TRANSITION: Cut
- TYPE: [LIVE] -- 30 seconds

## Scene 15: Live Recipe Demo (5:15 - 6:10)

- TALKING POINTS: Walk through full pasta cook with dashboard visible.
- - Tap Recipes > Pasta. Step 1: "Fill pot, set to high"
- - Watch temp climb on burner card
- - Step 2: "Waiting for rolling boil..." -- boil detected! "Rolling boil!"
- - "It knew my water was boiling before I did."
- - Step 3: Add pasta, tap Confirm. Step 4: 8-min timer with progress bar.
- VISUAL: Split view -- phone dashboard on left, actual stove on right
- IMAGE: Live footage (split screen or alternating)
- MOTION: handheld, documentary feel, genuine cooking
- TRANSITION: Cut
- TYPE: [LIVE] -- 55 seconds -- CENTERPIECE DEMO

## Scene 16: Multiple Burners (6:10 - 6:20)

- TALKING POINTS: "It tracks all four burners independently. Two pots going? No problem."
- VISUAL: Dashboard showing 2-3 active burners, pan across actual stove
- IMAGE: Live footage
- MOTION: static dashboard, handheld pan
- TRANSITION: Cut
- TYPE: [LIVE] -- 10 seconds

## Scene 17: The Comparison (6:20 - 6:30)

- LEFT SIDE: Timer App
- "8:00" counting down
- Nothing else.
- "One is guessing."

- RIGHT SIDE: StoveIQ
- Thermal heatmap
- Burner cards + live temps
- Recipe progress bar, "Rolling boil!"
- "The other one is watching."

## Chapter 5: The Recipe System

- 6:30 - 8:00 | 4 scenes
- Pull back the curtain on JSON state machines with thermal triggers. Make the audience want to contribute.

## Scene 18: How Recipes Work (6:30 - 7:10)

- NARRATION: "Recipes are JSON state machines. Each step has a description, a trigger, and a coaching message. Triggers are thermal -- boil, target, food_drop..."
- VISUAL: VS Code showing pasta.json with animated callouts, then recipe flow diagram
- ALSO: Quick cut to seared-steak.json -- highlight 'PAN IS SCREAMING HOT!' and 'FLIP NOW!'
- IMAGE: Screen capture (VS Code + animated diagram)
- MOTION: static code, animated overlays
- TRANSITION: Cut
- TYPE: [VO] -- 40 seconds

## Scene 19: Recipe Library (7:10 - 7:30)

- NARRATION: "Six recipes built in. But the real play is the community. Fork it, write a JSON file, test in simulation mode, submit a PR."
- VISUAL: GitHub /recipes directory, click into category folders, PR template
- IMAGE: Screen capture (GitHub)
- TEXT: "Fork. Write JSON. Submit PR."
- MOTION: static (screen capture with cursor)
- TRANSITION: Cut
- TYPE: [VO] -- 20 seconds

## Scene 20: Simulation Mode (7:30 - 7:50)

- TALKING POINTS: "Don't want to cook to test a recipe? Simulation mode. Drag the temperature slider, watch recipe steps advance."
- VISUAL: Dashboard in sim mode, dragging temp slider, recipe steps auto-advancing
- IMAGE: Phone screen recording + live footage
- TEXT: "Test recipes without cooking"
- MOTION: static/screen capture
- TRANSITION: Cut
- TYPE: [LIVE] -- 20 seconds

## Scene 21: Recipe JSON Close-Up (7:50 - 8:00)

- LEFT: JSON Recipe File
- 5 fields per step:
- desc, target_temp, trigger,
- timer_sec, coach_msg
- Steps highlight as they activate

- RIGHT: Dashboard Running Recipe
- Each step activates in real-time
- JSON step highlights in sync
- "Five fields. One recipe. Fork the repo."

## Chapter 6: What's Next + CTA

- 8:00 - 9:00 | 3 scenes
- Point to resources, tease the roadmap, direct call to action.

## Scene 22: Resources (8:00 - 8:25)

- NARRATION: "Everything is on GitHub -- firmware, recipes, hardware files, enclosure models. Hackaday.io has the full build log. Links in the description."
- VISUAL: Quick montage of project links with QR codes: Hackaday.io, GitHub repo, recipes dir
- IMAGE: Screen capture + AI-generated QR graphics
- TEXT: URLs + QR codes
- MOTION: static
- TRANSITION: Cut
- TYPE: [VO] -- 25 seconds

## Scene 23: What's Coming (8:25 - 8:45)

- NARRATION: "Next up -- a proper PCB. Open-source KiCad files. And 100 community recipes by end of year."
- VISUAL: KiCad PCB layout/render, GitHub Issues page, recipe count target
- IMAGE: Screen capture (KiCad) + AI-generated PCB render
- TEXT: "No more breadboard." + "100 community recipes by end of 2026"
- MOTION: gentle-zoom on PCB, static for GitHub
- TRANSITION: Cut
- TYPE: [VO] -- 20 seconds

## Scene 24: Call to Action / End Card (8:45 - 9:00)

- TALKING POINTS:
- - "Build one. It's two boards and four wires."
- - "Contribute a recipe. Fork the repo."
- - "Let's make cooking apps obsolete."
- - "Subscribe for the build series."
- - "Star the repo on GitHub."
- VISUAL: On-camera, holding the assembled device, then end card
- IMAGE: Live footage + end card graphic
- TEXT: Subscribe button, GitHub link, Hackaday.io link
- MOTION: static
- MUSIC: Fade out at 8:55
- TYPE: [LIVE] -- 15 seconds

## Production Plan Summary

- Total Chapters: 6
- Total Scenes: 24
- Estimated Runtime: ~9 minutes
- Live footage scenes: 14 (workbench, cooking demo, on-camera)
- Screen capture scenes: 5 (terminal, GitHub, VS Code, dashboard)
- AI-generated graphics: 4 (title card, QR, PCB render, comparison)
- Graphic overlays needed: 9 (wiring diagram, price breakdown, etc.)
- Narration: ~1,050 words voiceover + ~2 min live talking points
- Music: Upbeat lo-fi maker track, fade in at 0:50, 12% under VO
- Key moments to nail:
- Scene 11: First Light (thermal reveal -- thumbnail moment)
- Scene 15: Live Recipe Demo (centerpiece proof, 55 seconds)
- Scene 17: Timer vs StoveIQ side-by-side comparison

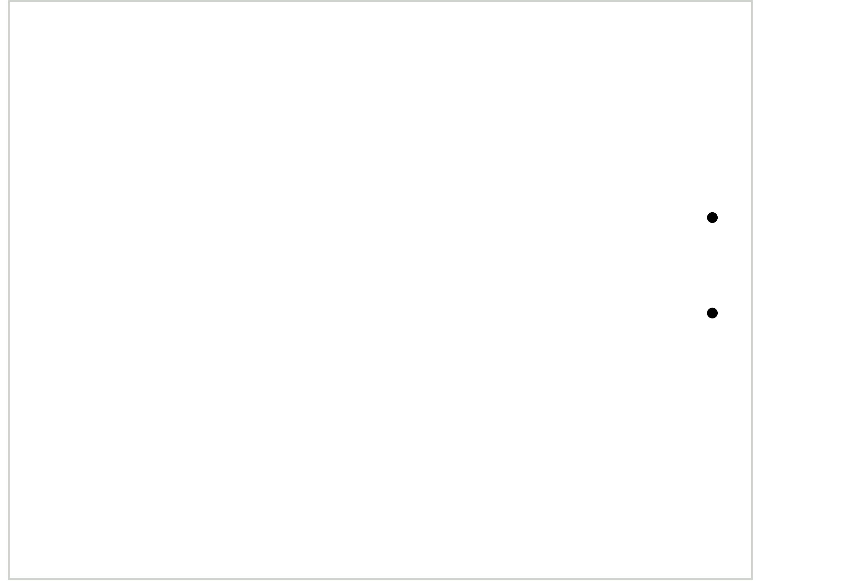
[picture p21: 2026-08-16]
hardware/pcb/renders/layout-bottom.png

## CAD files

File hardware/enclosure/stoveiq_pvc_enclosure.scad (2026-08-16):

// StoveIQ PVC Pipe Enclosure — Parametric Split-Tube Design
// Open-source hardware: CERN-OHL-P v2
// Nick DeMarco — 2026-04-10
//
// CONCEPT:
//   1.5" Schedule 40 PVC pipe, cut in half lengthwise with a hacksaw.
//   Lower half (sensor half):  MLX90640 breakout + 14mm camera window
//   Upper half (ESP32 half):   ESP32-S3-DevKitC-1 + USB-C exit notch
//   Snap halves together with zip ties through OD grooves.
//   Whole tube slips into a 3D-printed bracket that mounts under the cabinet.
//   Rotate bracket to aim — tighten one M3 screw to lock angle.
//
// BUILD NOTES:
//   - "Sensor half" and "ESP32 half" are 3D-printed SHELLS, not cut real PVC.
//     OR: Use real PVC pipe + print only the alignment/bracket pieces.
//   - For pure 3D-print approach: print both halves in ASA/PETG at 35% infill.
//   - For hybrid approach: buy 6" of 1.5" PVC, cut in half,
//     glue/press-fit printed standoff inserts into each half.
//
// RENDER MODES (set at bottom of file):
//   SHOW_SENSOR_HALF  = true/false
//   SHOW_ESP32_HALF   = true/false
//   SHOW_END_CAP      = true/false
//   SHOW_BRACKET      = true/false
//   SHOW_ASSEMBLY     = true   (positions all parts together)
//   SHOW_COMPONENTS   = true   (ghost PCB overlay for fit check)
//
// PRINT SETTINGS:
//   Material:   PETG (indoor) or ASA (outdoor)
//   Layer:      0.2mm
//   Infill:     35% gyroid
//   Supports:   NO (all surfaces designed support-free when printed flat-face-down)
//   Perimeters: 3 (for strength around screw bosses)

/* [Pipe Dimensions — 1.5" Sch 40 PVC] */
PIPE_OD = 48.26;      // Outer diameter (mm) — 1.900 inches
PIPE_ID = 40.89;      // Inner diameter (mm) — 1.610 inches
PIPE_L  = 120.0;      // Total tube length (mm)
// Wall thickness = (OD - ID) / 2 = 3.685mm

/* [MLX90640 Breakout (Adafruit 4469)] */
SENSOR_W    = 25.4;   // Board width (mm)
SENSOR_L    = 25.4;   // Board length (mm)
SENSOR_T    = 1.6;    // PCB thickness (mm)
WIN_D       = 14.0;   // Camera window hole diameter (mm) — clears 110° FoV
WIN_Z       = 30.0;   // Window position along pipe from sensor-end (mm)

/* [ESP32-S3-DevKitC-1] */
ESP_W       = 25.5;   // Board width (mm)
ESP_L       = 68.58;  // Board length (mm)
ESP_T       = 1.6;    // PCB thickness (mm)
USBC_W      = 13.0;   // USB-C notch width (mm) — extra for cable clearance
USBC_H      = 8.0;    // USB-C notch height (mm)

/* [Shared Mechanical] */
WALL        = 3.685;  // Shell wall thickness = PVC wall (matches real pipe)
STANDOFF_H  = 3.0;    // PCB standoff height (mm)
STANDOFF_OD = 4.5;    // Standoff boss OD (mm)
TAP_HOLE    = 2.2;    // M2 tap diameter (mm)
TAB_W       = 4.5;    // Alignment tab width (mm)
TAB_H       = 2.0;    // Alignment tab height (protrusion) (mm)
TAB_TOL     = 0.3;    // Tab-to-slot clearance (mm)
TAB_Z1      = 20.0;   // First tab position along pipe (mm)
TAB_Z2      = 100.0;  // Second tab position (mm)
GROOVE_W    = 2.5;    // Zip-tie groove width (mm)
GROOVE_D    = 1.5;    // Zip-tie groove depth (mm)
GROOVE_Z1   = 15.0;   // First groove position (mm)
GROOVE_Z2   = 105.0;  // Second groove position (mm)

/* [End Cap] */
CAP_T       = 4.0;    // Cap flange thickness (mm)
CAP_SPIGOT  = 10.0;   // Spigot length (press-fit into pipe ID) (mm)
CAP_FIT     = 0.4;    // Press-fit tolerance (mm) — print slightly undersize

/* [Mounting Bracket] */
BKT_PLATE_W = 62.0;   // Plate width (mm)
BKT_PLATE_L = 42.0;   // Plate length — cabinet contact (mm)
BKT_PLATE_T = 3.0;    // Plate thickness (mm)
BKT_ARM_T   = 3.5;    // Cradle arm wall thickness (mm)
BKT_HOLE_D  = 4.5;    // Screw hole diameter (#8 or M4)
BKT_HOLE_SP = 40.0;   // Hole spacing (center-to-center) (mm)

/* [Render Mode] */
SHOW_SENSOR_HALF  = true;
SHOW_ESP32_HALF   = false;
SHOW_END_CAP      = false;
SHOW_BRACKET      = false;
SHOW_ASSEMBLY     = false;  // override: positions all parts
SHOW_COMPONENTS   = false;  // ghost PCBs for clearance check

$fn = 64;

// ============================================================
// DERIVED VALUES
// ============================================================
PIPE_WALL   = (PIPE_OD - PIPE_ID) / 2;  // 3.685mm
R_OUT       = PIPE_OD / 2;
R_IN        = PIPE_ID / 2;

// ============================================================
// MODULE: HALF SHELL
// Pipe axis = Z. Split plane = Y=0 (flat faces).
// upper=true  → positive-Y half (ESP32 half, curved face up)
// upper=false → negative-Y half (sensor half, curved face down)
// ============================================================
module half_shell(upper=true) {
    // The D-shaped cross section:
    //  - Outer arc = pipe OD (curved wall)
    //  - Inner arc = pipe ID (curved bore)
    //  - Flat chord = connects the two at Y=0

    difference() {
        union() {
            // Outer arc half
            difference() {
                cylinder(h=PIPE_L, r=R_OUT, center=false);
                cylinder(h=PIPE_L + 2, r=R_IN, center=false, $fn=64);
                if (upper)
                    translate([-R_OUT-1, -(R_OUT+1), -0.5])
                        cube([2*(R_OUT+1), R_OUT+1, PIPE_L+1]);  // remove -Y half
                else
                    translate([-R_OUT-1, 0, -0.5])
                        cube([2*(R_OUT+1), R_OUT+1, PIPE_L+1]);  // remove +Y half
            }

            // Flat closing plate (D-face)
            // Width = pipe ID chord = 2*R_IN
            // Thickness = pipe wall (WALL)
            if (upper)
                translate([-R_IN, 0, 0])
                    cube([2*R_IN, WALL, PIPE_L]);
            else
                translate([-R_IN, -WALL, 0])
                    cube([2*R_IN, WALL, PIPE_L]);
        }

        // Zip-tie grooves on OD (circumferential ring groove)
        for (gz = [GROOVE_Z1, GROOVE_Z2]) {
            translate([0, 0, gz - GROOVE_W/2])
            difference() {
                cylinder(h=GROOVE_W, r=R_OUT + 0.1);
                cylinder(h=GROOVE_W + 0.1, r=R_OUT - GROOVE_D);
            }
        }
    }
}


// ============================================================
// MODULE: SENSOR HALF (lower — faces stove)
// ============================================================
module sensor_half() {
    difference() {
        half_shell(upper=false);

        // Camera window — radial bore through curved wall at WIN_Z
        // Drill direction: from bottom (+Y is into the half from outside)
        translate([0, -R_OUT - 2, WIN_Z])
            rotate([-90, 0, 0])
                cylinder(h=PIPE_OD + 4, r=WIN_D/2);

        // Alignment slots (receive tabs from ESP32 half)
        for (tz = [TAB_Z1, TAB_Z2]) {
            translate([-(TAB_W + TAB_TOL)/2,
                       -(TAB_H + TAB_TOL) - WALL,
                        tz - 1.75])
                cube([TAB_W + TAB_TOL,
                      TAB_H + TAB_TOL,
                      3.5]);
        }
    }

    // Standoffs for MLX90640 breakout inside lower half
    // Board positioned: centered on X, near the sensor window end
    sb_z0 = WIN_Z + 5;  // board starts 5mm past camera window
    standoff_positions = [
        [ SENSOR_W/2 - 3, sb_z0 + 3],
        [-SENSOR_W/2 + 3, sb_z0 + 3],
        [ SENSOR_W/2 - 3, sb_z0 + SENSOR_L - 3],
        [-SENSOR_W/2 + 3, sb_z0 + SENSOR_L - 3]
    ];

    for (sp = standoff_positions) {
        translate([sp[0], -WALL, sp[1]])
            rotate([90, 0, 0])
            difference() {
                cylinder(h=STANDOFF_H, r=STANDOFF_OD/2);
                translate([0, 0, -0.5])
                    cylinder(h=STANDOFF_H + 1, r=TAP_HOLE/2);
            }
    }
}


// ============================================================
// MODULE: ESP32 HALF (upper — faces cabinet)
// ============================================================
module esp32_half() {
    difference() {
        half_shell(upper=true);

        // USB-C cable exit notch at Z=0 end (cable exits toward one end)
        // Cut a U-channel through the flat face and pipe end wall
        translate([-USBC_W/2, -1, -0.5])
            cube([USBC_W, WALL + 3, USBC_H + 0.5]);

        // Alignment tab slots for mating (receive tabs from sensor side)
        // These are NOT needed on the ESP half — the ESP half HAS the tabs.
        // (slots are on sensor half; tabs are on ESP half — see union below)
    }

    // Alignment tabs (protrude from flat face at Y=0, into sensor half slot)
    for (tz = [TAB_Z1, TAB_Z2]) {
        translate([-TAB_W/2, 0, tz - 1.5])
            cube([TAB_W, TAB_H, 3.0]);
    }

    // Standoffs for ESP32-S3-DevKitC-1 inside upper half
    // USB-C end is at Z=0; board runs from Z=7 to Z=7+68.58
    eb_z0 = 7.0;
    esp_standoff_positions = [
        [ ESP_W/2 - 3, eb_z0 + 3],
        [-ESP_W/2 + 3, eb_z0 + 3],
        [ ESP_W/2 - 3, eb_z0 + ESP_L - 3],
        [-ESP_W/2 + 3, eb_z0 + ESP_L - 3]
    ];
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

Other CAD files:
hardware/enclosure/stoveiq_enclosure.scad

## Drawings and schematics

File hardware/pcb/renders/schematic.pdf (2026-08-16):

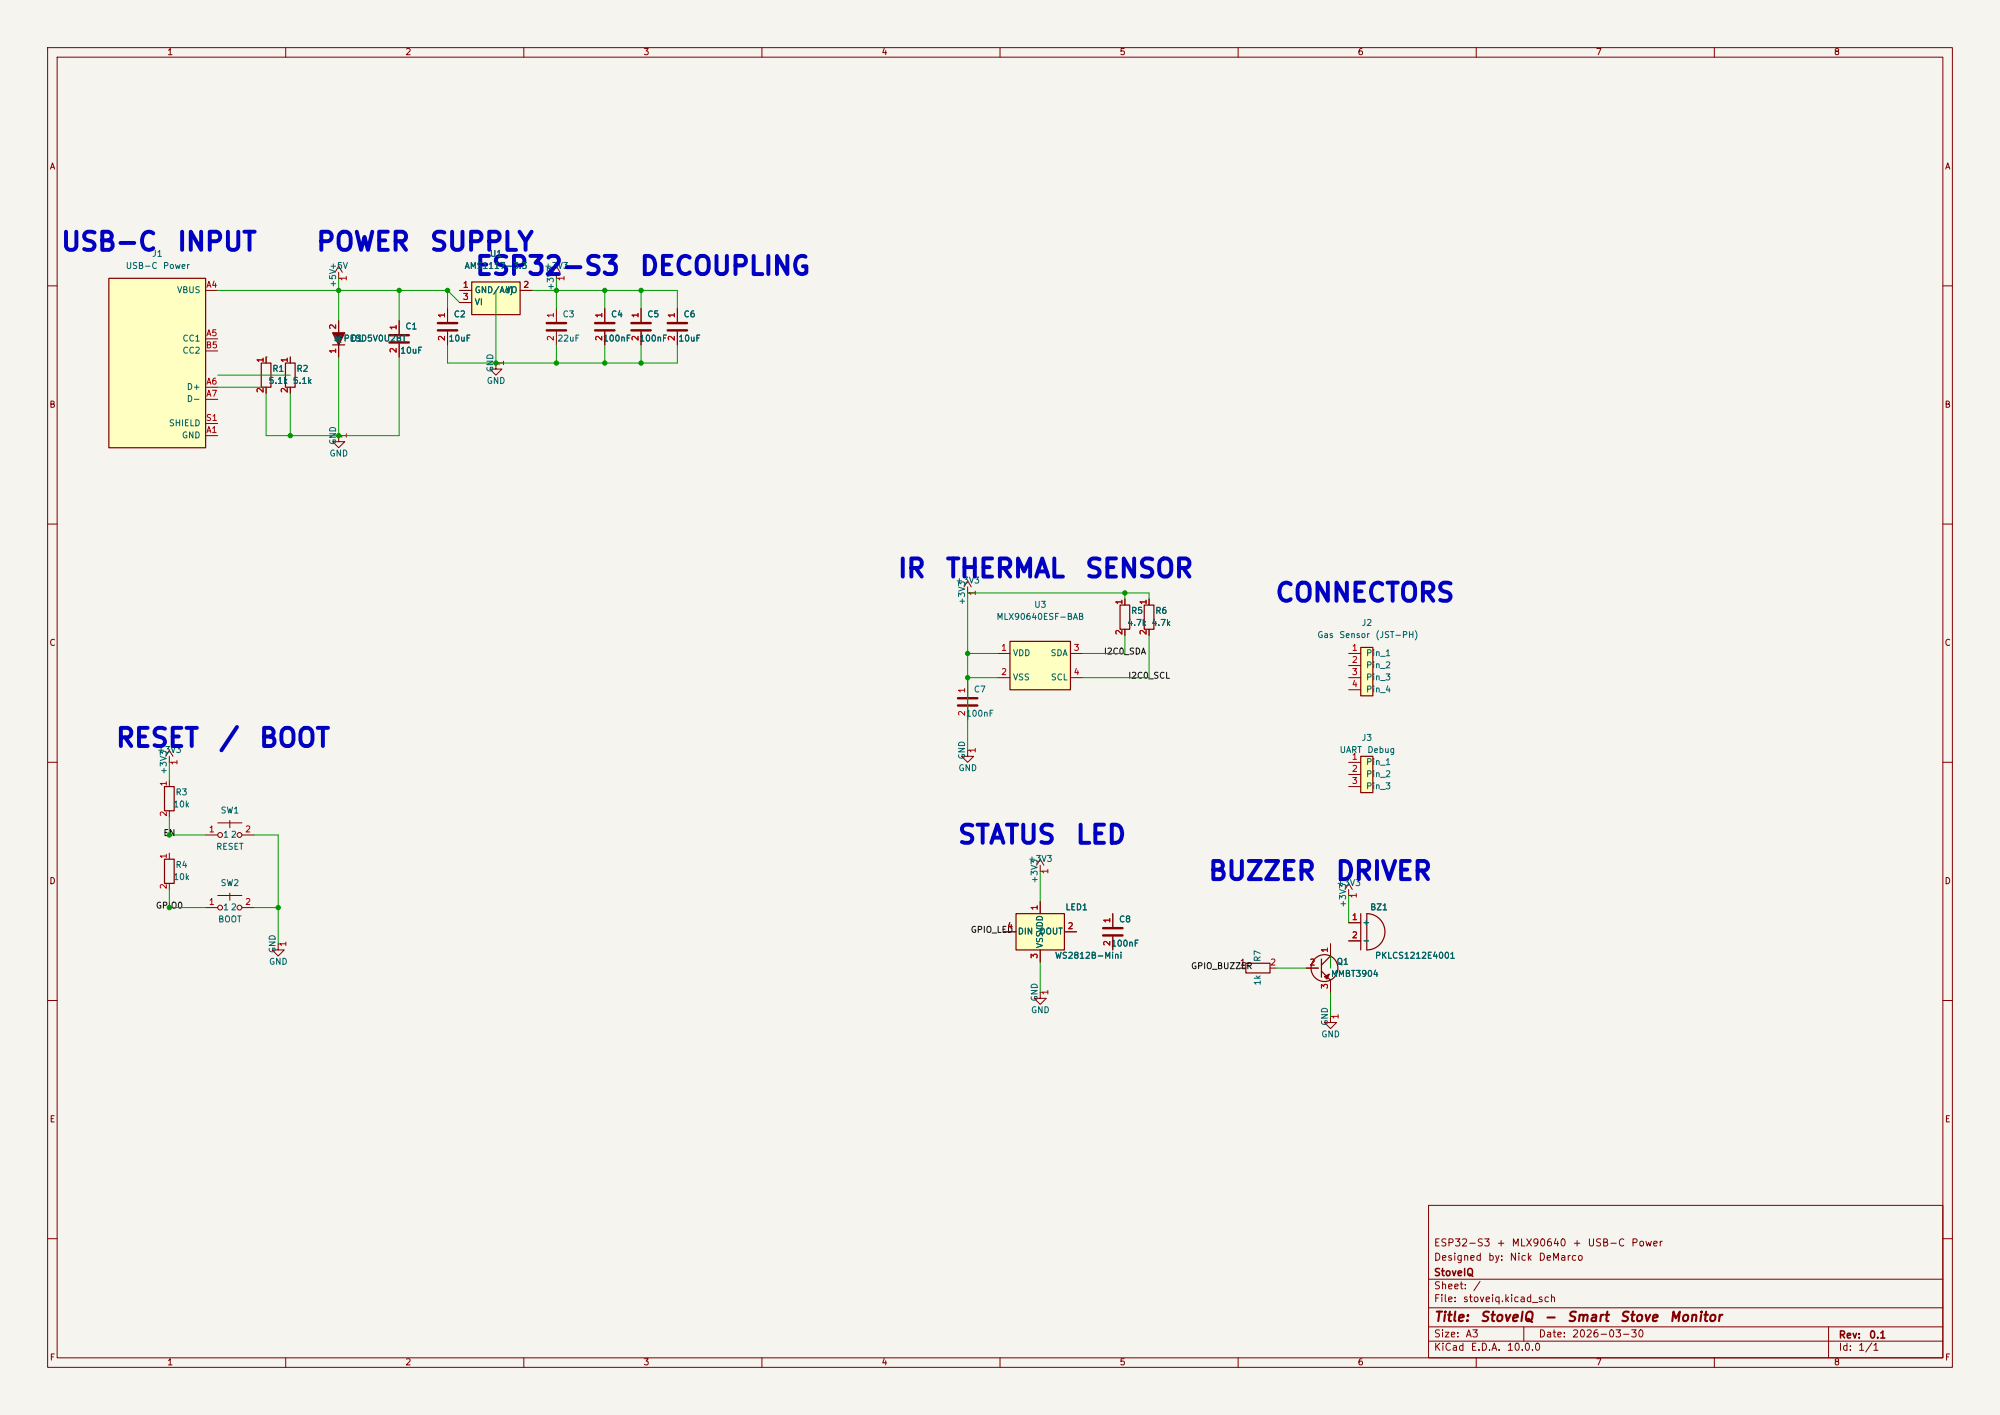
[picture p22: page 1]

ESP32-S3 + MLX90640 + USB-C Power
Designed by: Nick DeMarco
StoveIQ
Sheet: /
File: stoveiq.kicad_sch
Title: StoveIQ - Smart Stove Monitor

Size: A3 | Rev: 0.1 | F Date: 2026-03-30 KiCad E.D.A. 10.0.0

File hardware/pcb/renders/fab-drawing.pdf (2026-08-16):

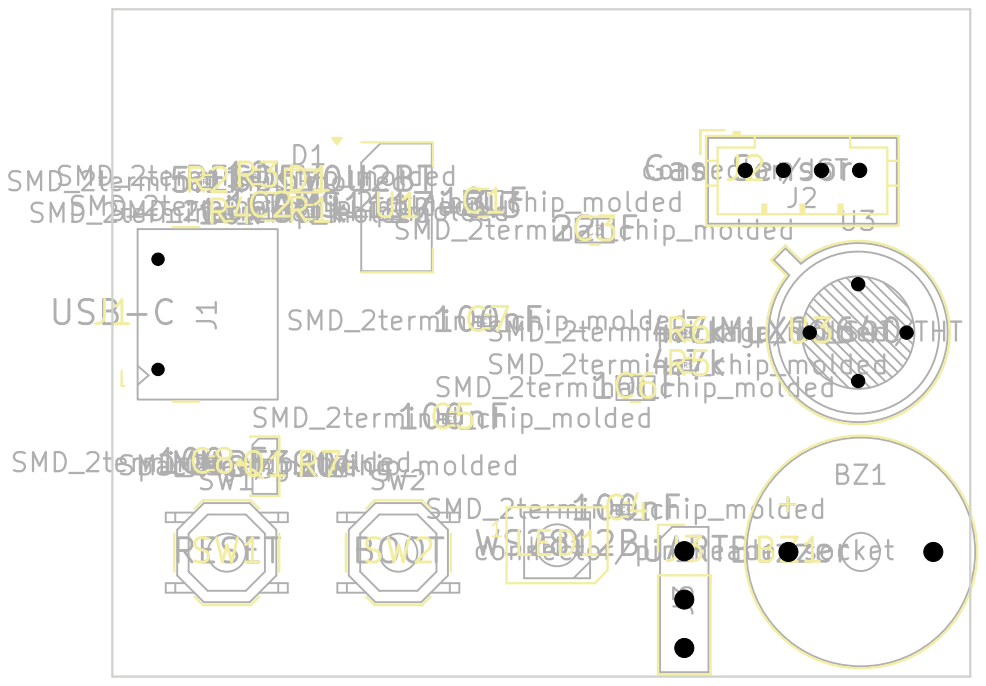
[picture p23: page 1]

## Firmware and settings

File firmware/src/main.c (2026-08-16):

/**
 * main.c -- StoveIQ Open Source firmware entry point
 *
 * ESP32: Init NVS, check for stored WiFi creds or start BLE
 *        provisioning, then launch the 3-task cooking pipeline.
 *
 * Emulator: Run thermal scenarios through the cooking engine
 *           to demonstrate burner detection and alerts.
 *
 * SPDX-License-Identifier: MIT
 */

#include "stoveiq_types.h"
#include "sensor.h"
#include "cooking_engine.h"
#include "tasks.h"
#include <stdio.h>
#include <string.h>

#define STOVEIQ_FW_VERSION "1.0.0"

/* ================================================================== */
/*  Native / Emulator entry point                                      */
/* ================================================================== */

#ifdef CONFIG_STOVEIQ_USE_EMULATOR

#include "thermal_emulator.h"
#include "scenarios/scenarios.h"
#include <unistd.h>

/**
 * Demo: Run a cooking scenario through the cooking engine.
 * Shows burner detection, state tracking, and alert generation.
 */
static void run_cooking_demo(void)
{
    printf("\n--- StoveIQ Cooking Engine Demo ---\n\n");

    sensor_init();
    sensor_emu_set_scenario(&scenario_all_burners);

    stoveiq_config_t config = STOVEIQ_CONFIG_DEFAULTS;
    cooking_engine_t engine;
    cooking_engine_init(&engine, &config);

    float frame[STOVEIQ_FRAME_PIXELS];
    float dt = 0.25f;  /* 4Hz */
    int total_frames = (int)(120.0f / dt);  /* 2 minutes */

    for (int i = 0; i < total_frames; i++) {
        float t = (float)i * dt;
        uint32_t ms = (uint32_t)(t * 1000.0f);

        sensor_emu_set_time(t);
        sensor_err_t err = sensor_read_frame(frame);
        if (err != SENSOR_OK) continue;

        thermal_snapshot_t snap = {0};
        memcpy(snap.frame, frame, sizeof(frame));
        snap.max_temp = sensor_get_max_temp(frame);
        snap.ambient_temp = sensor_get_ambient(frame);
        snap.timestamp_ms = ms;

        cooking_engine_process(&engine, &snap);

        if (i % 32 == 0) {
            printf("t=%5.0fs  max=%.1fC  amb=%.1fC  burners=%d",
                   t, snap.max_temp, snap.ambient_temp, snap.burner_count);
            for (int b = 0; b < snap.burner_count; b++) {
                const char *states[] = {"OFF", "HEAT", "STBL", "COOL"};
                printf("  [B%d:%.0fC/%s]", b,
                       snap.burners[b].current_temp,
                       states[snap.burners[b].state]);
            }
            printf("\n");
        }
    }

    int alert_count;
    const cook_alert_t *alerts = cooking_engine_get_alerts(&engine, &alert_count);
    if (alert_count > 0) {
        printf("\nAlerts generated: %d\n", alert_count);
        const char *alert_names[] = {
            "BOIL", "SMOKE_POINT", "PREHEATED", "FORGOTTEN", "FAULT"
        };
        for (int i = 0; i < alert_count; i++) {
            printf("  [%s] burner=%d temp=%.1fC t=%ums\n",
                   alert_names[alerts[i].type],
                   alerts[i].burner_id, alerts[i].temp,
                   alerts[i].timestamp_ms);
        }
    }

    printf("\nCooking demo complete.\n");
}

/**
 * Demo: Run the threaded pipeline for a few seconds.
 */
static void run_threaded_demo(void)
{
    printf("\n--- Threaded Pipeline Demo (10 seconds) ---\n\n");

    sensor_init();
    sensor_emu_set_scenario(&scenario_single_burner_30min);

    tasks_config_t config;
    config.config = (stoveiq_config_t)STOVEIQ_CONFIG_DEFAULTS;

    tasks_start(&config);
    sleep(10);

    printf("\nStopping tasks...\n");
    tasks_stop();
    printf("Threaded demo complete.\n");
}

/* PlatformIO defines UNIT_TEST when building the test runners, which bring
 * their own main() from Unity. Without this guard the emulator demo main()
 * and the test main() collide at link time. */
#ifndef UNIT_TEST
int main(void)
{
    printf("StoveIQ Open Source v%s (emulator)\n", STOVEIQ_FW_VERSION);
    printf("=========================================================\n");

    run_cooking_demo();
    run_threaded_demo();

    return 0;
}
#endif /* !UNIT_TEST */

/* ================================================================== */
/*  ESP32-S3 entry point                                               */
/* ================================================================== */

#elif defined(CONFIG_STOVEIQ_TARGET_ESP32)

#include "ble_provision.h"
#include "nvs_flash.h"
#include "esp_log.h"
#include "esp_event.h"
#include "esp_netif.h"
#include "esp_wifi.h"

static const char *TAG = "main";
static ble_provision_ctx_t s_prov_ctx;

static void on_provisioning_complete(const wifi_creds_t *creds, void *ctx)
{
    (void)ctx;
    ESP_LOGI(TAG, "Provisioning complete: SSID=%s", creds->ssid);
    ble_provision_stop(&s_prov_ctx);

    tasks_config_t config;
    config.config = (stoveiq_config_t)STOVEIQ_CONFIG_DEFAULTS;
    tasks_start(&config);
}

static void on_provisioning_error(prov_error_t error, void *ctx)
{
    (void)ctx;
    ESP_LOGE(TAG, "Provisioning error: 0x%02x", error);
}

void app_main(void)
{
    ESP_LOGI(TAG, "StoveIQ Open Source v%s", STOVEIQ_FW_VERSION);

    /* Init NVS */
    esp_err_t ret = nvs_flash_init();
    if (ret == ESP_ERR_NVS_NO_FREE_PAGES ||
        ret == ESP_ERR_NVS_NEW_VERSION_FOUND) {
        ESP_ERROR_CHECK(nvs_flash_erase());
        ret = nvs_flash_init();
    }
    ESP_ERROR_CHECK(ret);

    /* Init networking stack — required before WiFi provisioning */
    ESP_ERROR_CHECK(esp_netif_init());
    ESP_ERROR_CHECK(esp_event_loop_create_default());
    esp_netif_create_default_wifi_sta();
    wifi_init_config_t wifi_cfg = WIFI_INIT_CONFIG_DEFAULT();
    ESP_ERROR_CHECK(esp_wifi_init(&wifi_cfg));

    /* Check for stored WiFi creds (from BLE provisioning or web UI) */
    wifi_creds_t stored_creds;
    if (ble_provision_has_stored_creds(&stored_creds)) {
        ESP_LOGI(TAG, "Found stored WiFi: SSID=%s", stored_creds.ssid);
        tasks_config_t config;
        config.config = (stoveiq_config_t)STOVEIQ_CONFIG_DEFAULTS;
        tasks_start(&config);
    } else {
        ESP_LOGI(TAG, "No stored WiFi — starting BLE provisioning");
        printf("\n");
        printf("*******************************************\n");
        printf("*  BLE Provisioning Active                *\n");
        printf("*  Connect with ESP BLE Prov app          *\n");
        printf("*  PoP: stoveiq-setup                     *\n");
        printf("*******************************************\n\n");

        ble_provision_init(&s_prov_ctx,
                           "StoveIQ", STOVEIQ_FW_VERSION,
                           on_provisioning_complete,
                           on_provisioning_error,
                           NULL);
        ble_provision_start(&s_prov_ctx);
    }
}

#else
#error "Define CONFIG_STOVEIQ_USE_EMULATOR or CONFIG_STOVEIQ_TARGET_ESP32"
#endif

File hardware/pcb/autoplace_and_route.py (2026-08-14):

#!/usr/bin/env python3
"""
StoveIQ PCB Auto-Place and Route
Uses KiCad's pcbnew Python API + Freerouting autorouter.

Pipeline:
1. Load board
2. Place all footprints with proper positioning
3. Add ground pour on B.Cu
4. Export Specctra DSN
5. Run Freerouting autorouter
6. Import routed SES back
7. Save board

Usage:
  /Applications/KiCad/KiCad.app/Contents/Frameworks/Python.framework/Versions/3.9/bin/python3.9 autoplace_and_route.py
"""

import os
import sys
import subprocess

# Add KiCad's Python packages
sys.path.insert(0, "/Applications/KiCad/KiCad.app/Contents/Frameworks/Python.framework/Versions/3.9/lib/python3.9/site-packages")
os.environ["DYLD_FRAMEWORK_PATH"] = "/Applications/KiCad/KiCad.app/Contents/Frameworks"

import pcbnew

# Board dimensions in mm
BOARD_W = 45.0
BOARD_H = 35.0
BOARD_ORIGIN_X = 100.0  # mm from sheet origin
BOARD_ORIGIN_Y = 80.0

# Convert mm to KiCad internal units (nanometers)
def mm(val):
    return pcbnew.FromMM(val)

def place_footprint(board, fp, x_mm, y_mm, angle_deg=0, layer="F.Cu"):
    """Place a footprint at given position."""
    fp.SetPosition(pcbnew.VECTOR2I(mm(x_mm), mm(y_mm)))
    if angle_deg != 0:
        fp.SetOrientationDegrees(angle_deg)
    if layer == "B.Cu":
        fp.Flip(fp.GetPosition(), False)
    print(f"  Placed {fp.GetReference():6s} ({fp.GetValue():20s}) at ({x_mm:.1f}, {y_mm:.1f}) {angle_deg}deg {'BACK' if layer == 'B.Cu' else ''}")

def main():
    pcb_path = os.path.join(os.path.dirname(os.path.abspath(__file__)), "stoveiq.kicad_pcb")
    dsn_path = pcb_path.replace(".kicad_pcb", ".dsn")
    ses_path = pcb_path.replace(".kicad_pcb", ".ses")
    freerouting_jar = os.path.join(os.path.dirname(os.path.abspath(__file__)), "..", "tools", "freerouting.jar")

    print("=" * 60)
    print("StoveIQ PCB Auto-Place and Route")
    print("=" * 60)

    # Step 1: Load board
    print("\n[1/7] Loading board...")
    board = pcbnew.LoadBoard(pcb_path)
    print(f"  Loaded: {pcb_path}")
    print(f"  Nets: {board.GetNetCount()}")

    footprints = list(board.GetFootprints())
    print(f"  Footprints: {len(footprints)}")

    if len(footprints) == 0:
        print("\n  No footprints on board yet. Running netlist import first...")
        print("  NOTE: You need to do 'Update PCB from Schematic' (F8) in KiCad first")
        print("  to transfer components from schematic to PCB.")
        print("  Then re-run this script.")
        sys.exit(1)

    # Step 2: Place footprints
    print("\n[2/7] Placing footprints...")

    # Board area: 100,80 to 145,115 (45x35mm)
    # Layout strategy:
    #   - USB-C (J1): left edge, centered vertically
    #   - LDO (U1): left-center, BACK SIDE for heat spreading
    #   - Input caps (C1, C2): near LDO input
    #   - Output cap (C3): near LDO output
    #   - ESP32-S3 module: center of board (it's the biggest component ~18x25mm)
    #   - ESP32 decoupling (C4, C5, C6): right next to ESP32 VDD pins
    #   - MLX90640 (U3): right edge, on thermal standoff
    #   - I2C pull-ups (R5, R6): between ESP32 and MLX90640
    #   - CC resistors (R1, R2): near USB-C
    #   - TVS diode (D1): near USB-C
    #   - WS2812B LED (LED1): front edge, visible
    #   - Buzzer (BZ1): front edge
    #   - Buzzer driver (Q1, R7): near buzzer
    #   - Reset/Boot (SW1, SW2): accessible edge
    #   - Pull-ups (R3, R4): near switches
    #   - JST connector (J2): right side
    #   - UART header (J3): right side, debug access
    #   - Mounting holes: 4 corners

    # Component placement map (reference -> (x_mm, y_mm, angle, layer))
    # Coordinates are absolute on the PCB sheet
    placements = {
        # Power input section (left side)
        "J1":   (103.0, 97.5, 0, "F.Cu"),      # USB-C connector, left edge
        "R1":   (107.0, 88.0, 0, "F.Cu"),       # CC1 pull-down
        "R2":   (109.0, 88.0, 0, "F.Cu"),       # CC2 pull-down
        "D1":   (109.0, 93.0, 0, "F.Cu"),       # TVS diode
        "C1":   (111.0, 97.5, 0, "F.Cu"),       # Input bulk cap

        # Voltage regulator (left-center, back side)
        "U1":   (115.0, 97.5, 0, "B.Cu"),       # AMS1117 LDO on BACK
        "C2":   (112.0, 103.0, 0, "B.Cu"),      # LDO input cap (back)
        "C3":   (118.0, 103.0, 0, "B.Cu"),      # LDO output cap (back)

        # ESP32-S3 module (center - this is ~18x25mm, dominates the board)
        # Module center at board center, shifted slightly right
        # Antenna end faces TOP edge (away from wall, toward room)
        "C4":   (125.0, 87.0, 0, "F.Cu"),       # ESP32 decoupling 100nF
        "C5":   (127.5, 87.0, 0, "F.Cu"),       # ESP32 decoupling 100nF
        "C6":   (130.0, 87.0, 0, "F.Cu"),       # ESP32 decoupling 10uF

        # Reset/Boot buttons (bottom left, accessible)
        "SW1":  (106.0, 111.0, 0, "F.Cu"),      # Reset button
        "SW2":  (112.0, 111.0, 0, "F.Cu"),      # Boot button
        "R3":   (106.0, 107.0, 0, "F.Cu"),      # EN pull-up 10k
        "R4":   (112.0, 107.0, 0, "F.Cu"),      # GPIO0 pull-up 10k

        # MLX90640 IR sensor (right edge, on standoff)
        "U3":   (141.0, 97.5, 0, "F.Cu"),       # IR sensor at right edge
        "R5":   (136.0, 92.0, 0, "F.Cu"),       # I2C SDA pull-up
        "R6":   (136.0, 95.0, 0, "F.Cu"),       # I2C SCL pull-up
        "C7":   (138.0, 103.0, 0, "F.Cu"),      # MLX90640 decoupling

        # Status LED (front, visible through enclosure)
        "LED1": (122.0, 112.0, 0, "F.Cu"),      # WS2812B status LED
        "C8":   (126.0, 112.0, 0, "F.Cu"),      # LED decoupling

        # Buzzer + driver (front right)
        "BZ1":  (133.0, 111.0, 0, "F.Cu"),      # Piezo buzzer
        "Q1":   (130.0, 107.0, 0, "F.Cu"),      # NPN driver
        "R7":   (128.0, 107.0, 90, "F.Cu"),     # Base resistor

        # Connectors (right side)
        "J2":   (142.0, 88.0, 0, "F.Cu"),       # JST gas sensor expansion
        "J3":   (142.0, 107.0, 0, "F.Cu"),      # UART debug header
    }

    placed = 0
    not_found = []
    for fp in footprints:
        ref = fp.GetReference()
        if ref in placements:
            x, y, angle, layer = placements[ref]
            place_footprint(board, fp, x, y, angle, layer)
            placed += 1
        elif ref.startswith("MH"):
            # Mounting holes already positioned in PCB file
            pass
        else:
            not_found.append(ref)

    print(f"\n  Placed: {placed}/{len(placements)}")
    if not_found:
        print(f"  Not in placement map: {not_found}")

    # Step 3: Add ground pour on bottom copper layer
    print("\n[3/7] Adding ground pour on B.Cu...")
    try:
        zone = pcbnew.ZONE(board)
        zone.SetIsRuleArea(False)
        zone.SetDoNotAllowTracks(False)
        zone.SetDoNotAllowVias(False)
        zone.SetDoNotAllowPads(False)
        zone.SetDoNotAllowCopperPour(False)
        zone.SetLayer(pcbnew.B_Cu)
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

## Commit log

2026-08-14 chore: adopt into the AgentArchitect Factory Model
    This repo now carries generated agents and orchestrator skills for the
    three disciplines it actually spans:
    hardware-dev firmware/, hardware/, enclosure/
    software-project the on-device web dashboard, calibration UI, sessions
    content-studio video/ — the YouTube build series
    Adds the provenance manifest and a routing block in CLAUDE.md (between
    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
2026-08-14 fix(firmware): repair the native emulator build
    The emulator target had not been buildable. Three separate faults:
    - build_src_filter listed src files as `+<src/foo.c>`, but the filter
    resolves relative to src_dir, so those patterns looked for
    firmware/src/src/*.c and matched nothing. Only the emulator/ tree
    compiled, and the link failed on an undefined main().
    - the vendored MLX90640 driver is ESP-IDF-only (driver/i2c.h). sensor.c
    already compiles it out under CONFIG_STOVEIQ_USE_EMULATOR, but the
    dependency finder builds everything in lib/ regardless — now ignored
    for this env.
    - tasks_stop() passed &pthread_t to pthread_join(), which takes the
    handle by value.
    `pio run -e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
2026-08-14 chore: ignore video render media, track the script and storyboard
    video/ held ~424MB of untracked binaries — a 167MB narration WAV, a 46MB
    music bed, 31 segment MP4s and a 36MB draft cut. That does not belong in a
    public repo, and all of it is re-derivable from the script and storyboard.
    Ignores video/* with exceptions for video/scripts/ and assemble_v1.py, so
    what enters the repo is the 132KB reproducible side: outline, script,
    storyboard, project.json and the assembly script. assets/ (AI-generated
    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
2026-08-14 feat(hardware): add the KiCad board design and enclosure models
    The PCB work existed only as untracked files in the pre-pivot working
    copy, so it had never been committed anywhere. Brought across so the
    board is buildable from a clone:
    - pcb/ — KiCad 9 project: schematic, layout, symbols, fab PDF, DSN/SES
    routing files, 3D renders, and the placement/routing helper scripts
    - enclosure/ — OpenSCAD model plus rendered views
    - README.md — component table (ESP32-S3-WROOM-1-N8R8, MLX90640ESF-BAB,
    AMS1117-3.3, WS2812B status LED, piezo buzzer, USB-C with ESD)
    Board is 2-layer FR4, 45x35mm. Editor artifacts (*.kicad_prl, backups,
    fp-info-cache) are ignored rather than tracked.
    Nothing f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
    [stoveiq.dsn, stoveiq.kicad_pcb, stoveiq.kicad_sch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]
2026-08-14 docs: tell the project's history in the README
    Add a Project History section covering the arc from multipurpose kitchen
    gadget to commercial safety product to abandoned product to personal
    open-source build, so readers understand why the repo contains a patent
    draft, a Kickstarter-grade BOM, and an unfabricated KiCad board.
    Also correct the parts of the README that described a build that no
    longer exists:
    - clone path was stoveiq-open, repo is stoveiq
    - uploadfs step removed; the web UI is embedded in web_server.c and
    firmware/data/ ships empty
    - device serves HTTPS on 443 and redirects port 80, not plain HTTP
    - enclosure files are OpenSCAD/FreeCAD sources, not STLs, and the
    current mo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
2026-08-16 fix(firmware): repair the calibration heatmap and refresh the TLS cert
    The calibration view rendered a solid black rectangle and never updated,
    which read as a dead thermal camera. The MLX90640 was fine the whole time.
    Three defects, all downstream of the sensor:
    - drawCal() guarded the heatmap on `temps.length===768`, which is always
    true for a Float32Array. Before the first frame landed it happily
    rendered the zero-filled array: mn=mx=0, range=1, every pixel cmap(0)
    -- solid black, indistinguishable from a failed sensor. Guard on a real
    haveFrame flag instead and show "Waiting for sensor data..." otherwise.
    - ws.onmessage stored each binary frame but never repainted, so the
    ov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
    [web_server.c]
2026-08-16 fix(firmware): show degree signs and emoji instead of escape sequences
    Eight \uXXXX escapes sat in HTML text and attribute context rather than
    inside JS string literals, so the browser never parsed them. On the device
    the settings panel read "Temp Offset: 0°C", the burner view offered
    "Calibrate boil (100°C)", and the two settings buttons were labelled
    "🍳 Cookware library" and "📊 Sessions & backup".
    Replaced those eight with the literal UTF-8 characters. The escapes that
    live inside JS strings are left alone — JS parses those correctly, and the
    emoji in the EVENTS and cookware tables already render fine.
    [web_server.c]
2026-08-16 fix(hardware): mate the enclosure halves and repair the board 3D views
    The SHOW_ASSEMBLY block rotated the ESP32 half 180 degrees about X and
    offset it by one pipe diameter. Rotating about X also flips Z, which sent
    the half to negative Z, so the assembly rendered as two tubes floating
    apart. Both halves are already modelled in their mated positions —
    sensor_half() in -Y, esp32_half() in +Y, sharing the split plane and the Z
    axis — so they need no transform at all.
    On the board, two footprints pointed at STEP files that KiCad 10 ships the
    footprint for but not the model, leaving bare pads where the USB-C
    receptacle and the thermal sensor should be. Repointed to same-family
    equivalents: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
    [stoveiq.kicad_pcb, stoveiq_pvc_enclosure.scad]
2026-08-16 docs: show the UI and document the hardware honestly
    The repo had a KiCad board, two OpenSCAD enclosures and a web UI, and the
    front page showed none of them. It now does.
    Screenshots (docs/images/) are the real interface, not mockups. The UI is
    embedded in web_server.c as a C string literal and the emulator build
    excludes that file, so there was no way to see it without flashing a board
    and standing at a hot stove. tools/ui-screenshots/ extracts the HTML and
    serves it against a synthetic four-burner cooktop that speaks the
    firmware's own WebSocket protocol — 4-byte LE timestamp plus 768 int16 at
    4Hz, status JSON at 2Hz, burner states and alert types taken from
    stoveiq_types.h. Provenance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
2026-08-16 docs: drop the YouTube and Hackaday links
    Neither exists. The banner pointed at hackaday.io's homepage rather than a
    project page — "coming soon" since April — and repeated a self-link to the
    repo the reader is already looking at. The same three links appeared again
    in a "Follow the Project" table at the bottom, along with a four-part video
    series that was never made.
    Removed the banner, the table and the series list. GitHub is the only place
    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
2026-08-16 ci: make both jobs build from a clean clone
    Neither job had passed since the badge was added. Four separate causes, all
    of them things that worked locally because the working tree held files a
    fresh checkout does not.
    Tests: test_integration.c included safety_monitor.h and wifi_mqtt.h, modules
    from the archived safety-product repo that were never carried over, so it
    had not compiled since the initial commit and it took the other two suites
    down with it. Deleted — 415 lines testing code that does not exist here.
    That exposed a second problem: all three suites sat flat in test/, so
    PlatformIO linked them into one binary and setUp/main collided. Moved each
    into its own directory, and guarded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
    [main.c]
2026-10-06 hardware: add the 2026-03-30 schematic ERC report next to its DRC report
    Same KiCad session as the tracked stoveiq-drc.rpt (run eight minutes
    earlier). 75 findings: 29 errors, 46 warnings, including 24 unconnected
    pins and one undriven power pin. Not re-verified against the current
    schematic; rerun ERC and DRC the next time the board is open.

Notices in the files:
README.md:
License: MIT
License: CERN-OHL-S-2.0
